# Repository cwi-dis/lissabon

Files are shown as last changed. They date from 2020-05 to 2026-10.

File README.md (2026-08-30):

# lissabon off-grid lighting control



Lissabon is an experiment in smart control over off-grid lighting. The intention is to provide a set of small dimmers, remotes and user interfaces that allow you to control lighting. The target application area is strictly low-voltage, battery operated and solar powered. 

> The project got its name from [Tuinpark Lissabon](https://www.tuinparklissabon.nl), an allotment (_"volkstuintje"_ in dutch) in Amsterdam, where the experiment was conducted... 

## Setting

The intended application area is an off-grid premise (holiday home, caravan, boat, etc) with solar cells backed by a 12V battery. Low-voltage LED lights are available as LED strips, MR-16/GU5.4 spots and various other forms, but control hardware - and especially smart home control hardware - is often geared towards use in a 110/220V environment where power is always available and not at a premium.

## Requirements

- _Day-to-day convenience_. Lights can be dimmed or turned on or off with a switch or knob on the fixture or close to it.
- _Predictiveness_. When you press the switch the light goes on or off, within a short time. 
- _Resilience_. In case of system malfunction this should be communicated to the user, and everything should go back to normal quickly. Individual lights should still be controllable on the spot. (All of this excepting a complete loss of battery power, obviously).
- _Low power consumption and very low idle power consumption_. When the lights are off the components should use very little power. So little that the individual components survive in winter, when there is preciously little sun to charge the battery, and the lights still come on when you return after a month of absence.
- _Affordable_. The cost of the control hardware should be reasonable, less than the cost of the lights they control.

The low-power requirement holds for dayly use, it is okay if the components use more power when installing new fixtures or reconfiguring the system.

## Power consumption

Preliminary analysis of the power consumption is availble in [doc/ble-power.md](doc/ble-power.md).

## Design choices

Lissabon is built on top of the [iotsa](https://github.com/cwi-dis/iotsa) Internet-of-Things framework, using the ESP32 system on a chip, which has WiFi, Bluetooth LE and low power support built in.

Lights are always eased on and off, not switched instantaneously. This looks cool, but it is also the intention that it makes the user less susceptible of any delay in operation.

> This is one of the things that needs to be tested formally.

During normal operation Bluetooth LE is used to communicate, and components are in a wake/sleep cycle. When awake they broadcast their existence with a BLE advertisement (consuming about 50mA). If not contacted within 0.2 seconds by a remote control they go into low power mode (consuming about 5mA) for 2 seconds. As the component has been inactive longer this 2 second sleep period will increase. When a local control (knob, touchpad) is operated the component awakes instantly.

> Deep sleep is not used, even though idle power consumption would go down to about 0.1mA: a wakeup from deep sleep is essentially a reboot, and would consume 100mA for about a second. This means that a deep sleep of less than 20 seconds is essentially a waste of power. This decision may be reconsidered in the future.

When the installation has to be reconfigured all components are sent a BLE instruction that will make them enable WiFi. They will keep WiFi enabled (consuming about 100mA) until they have not been contacted for 2 minutes. The configuration application (when written:-) will run on a smartphone or Raspberry PI that will also provide the WiFi Access Point (software base station).

> Using [igor](https://github.com/cwi-dis/igor) on a Raspberry PI as the basis for the control application needs to be investigated. It may be overkill, but it would allow things like waking PI once per day, and using a 3G/4G or Lorawan connection to "phone home" and report on the status of things like temperature, humidity level, battery level, etc)

## Components

### libLissabon

This is a shared library containing iotsa modules used by multiple other components. Various options are set using C-preprocessor defines, so the library is included as source in the components that actually use it.

### lissabonSimpleLight

A minimal example: a single on/off LED, controlled locally by a pushbutton and remotely over BLE. See `lissabonSimpleRemote` below.

### lissabonSimpleRemote

A minimal example: a pushbutton remote that toggles a `lissabonSimpleLight` (or any lissabon dimmer) on/off over BLE.

### lissabonDimmer

A dimmer, with buttons, touchpads, rotary control or neither. It is intended for LED lights, monochrome ledstrips or incandescant lights.

### lissabonLedstrip

A dimmer with buttons, touchpads or neither for smart (neopixel) RGB or RGBW ledstrips.

### lissabonRemote

A wireless LiPo-powered remote control that can control a predefined set of dimmers.

### lissabonController

A more elaborate remote control with a display. Incomplete. 

## Pictures

Lissabon Dimmer, plug-in variant with rotary control:
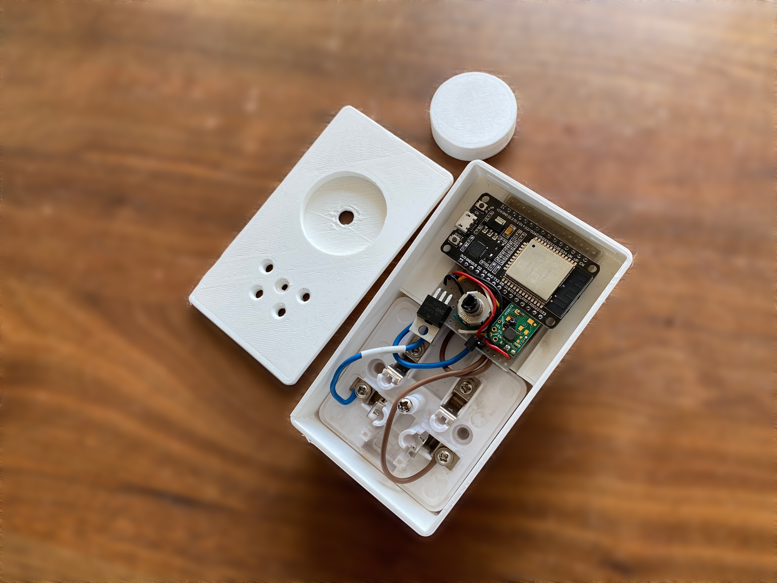
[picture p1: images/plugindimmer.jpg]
Plugin Dimmer


Lissabon Dimmer without controls, for use in inaccessible locations:
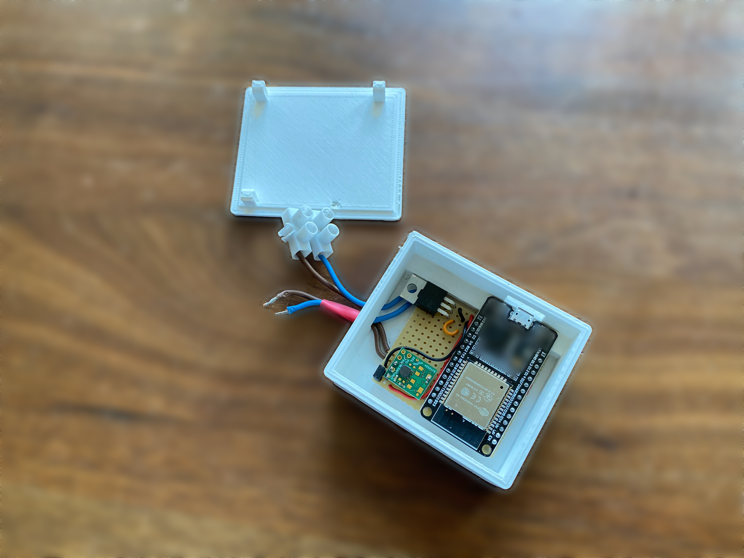
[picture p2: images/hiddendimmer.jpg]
Hidden Dimmer


Ledstrip dimmer, with brightness and color temperature touchpads:
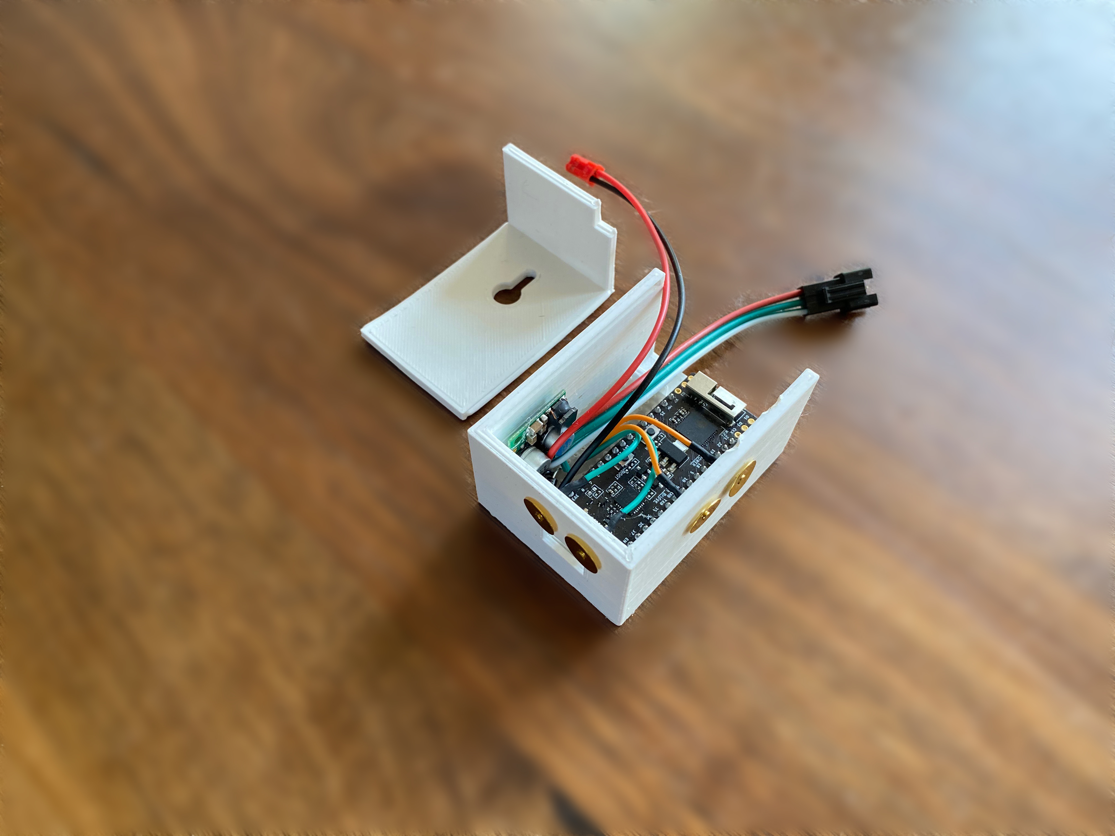
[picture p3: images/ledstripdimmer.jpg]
Ledstrip Dimmer


Wireless remote control, inside and outside with holder:
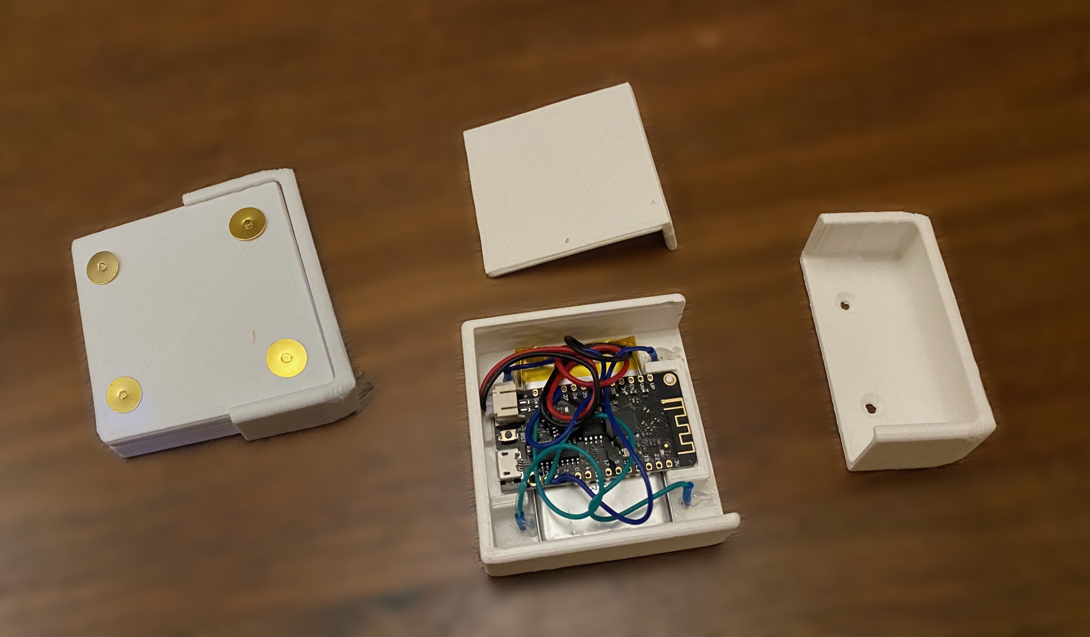
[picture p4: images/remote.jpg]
Wireless Remote


Controller: to be supplied

In situ pictures: to be supplied

## Construction notes

### Keep wiring away from the ESP32 antenna

Every lissabon appliance uses an ESP32 module with a PCB trace antenna at one end. Any
conductor in the antenna's near field (roughly 20mm, in any direction) detunes it and
costs BLE range. On deployed ledstrips, 20-35dB of lost range was traced to nothing more
than the 12V supply leads being dressed past the antenna.

This is not crosstalk: the thing being spoiled is the antenna's own tuning and
efficiency, so a pure-DC power lead does it just as well as a signal wire, and adding a
ground wire or ground pour near the antenna makes it *worse*, not better.

When building and boxing a unit:

- Mount the module so the antenna end faces open air, not the enclosure wall, the
  battery, or structural metal.
- Route *all* wiring (power and signal) out of the enclosure at the opposite end from the
  antenna.
- Twist the 12V supply pair, and twist or bundle other multi-wire runs, to minimise loop
  area.
- Orient the finished unit so the antenna end points away from any metal it is mounted on
  or near (e.g. an aluminium LED channel).

Symptom of getting this wrong: weak or highly variable BLE RSSI and connection drops that
clear up when the unit is moved or the wiring re-dressed. WiFi is far more tolerant (it
transmits ~15-20dB louder and falls back to slower bit rates), so a unit can have perfectly
good WiFi and unusable BLE from the same cause.

## ESP32 pinouts

I have been using three different boards in the various projects here. Naming of the ESP32 boards is sometimes confusing, so here are pictures of the board and their pinouts:

Lolin32 image and pinout:
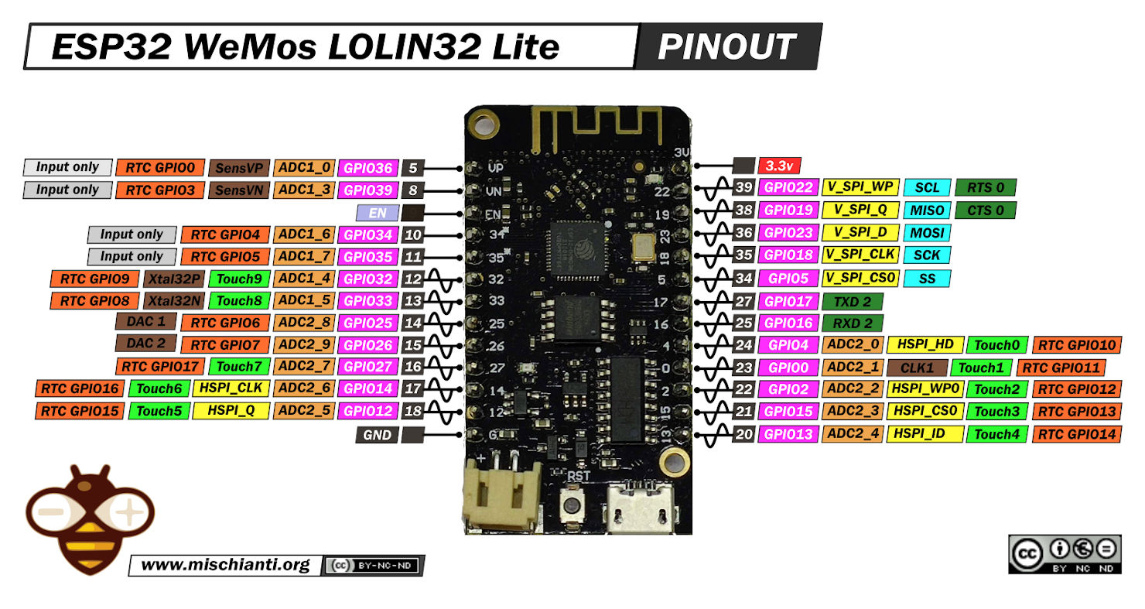
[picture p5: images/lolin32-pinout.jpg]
Lolin32 image and pinout


Esp32dev image and pinout:
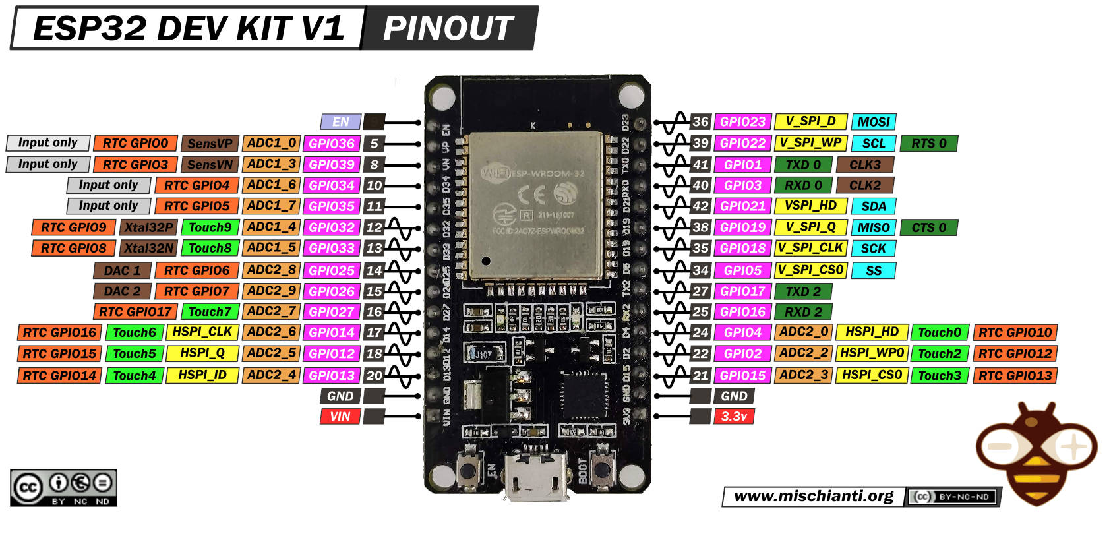
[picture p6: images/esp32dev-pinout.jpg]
esp32dev image and pinout


Pico32 image and pinout:
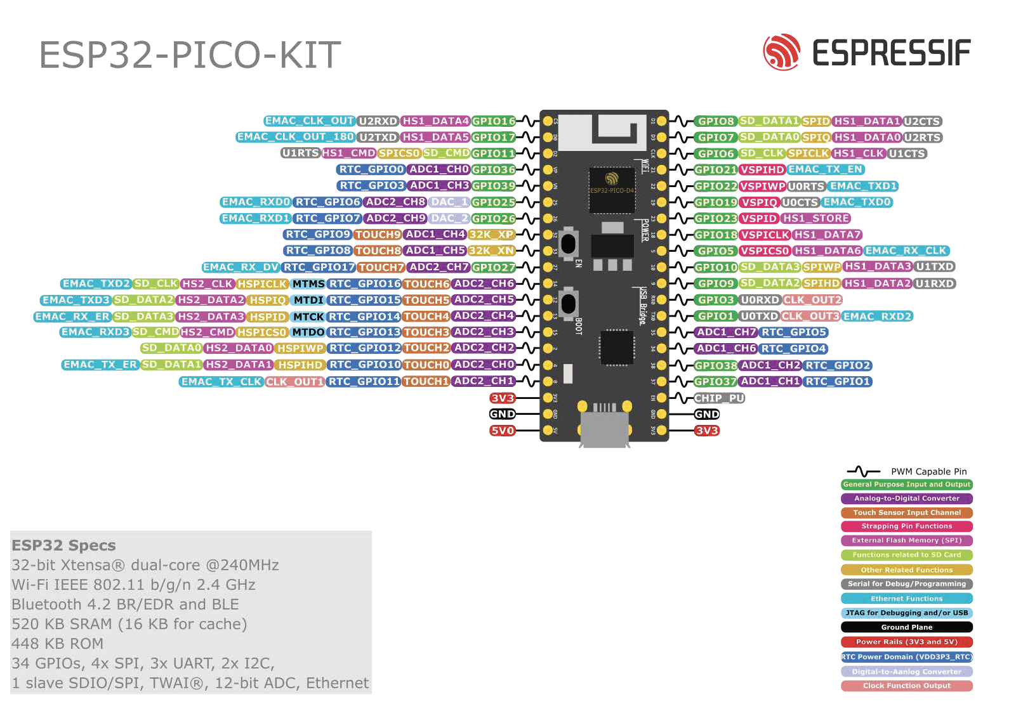
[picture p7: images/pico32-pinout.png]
pico32 image and pinout


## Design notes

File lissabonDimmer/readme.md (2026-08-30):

# lissabon Dimmer

This iotsa application implements a low-voltage dimmer using a MOSFET. Brighness 
and on/off are controlled either through a rotary encoder or through touchpads 
(selectable at build time), or even not at all (but read on).

Brightness and on/off state are inspectable and controllable over Bluetooth LE
and through a web or rest interface.

It is intended to be used in lighting applications,
probably off-grid.

## Hardware construction

The `extras` folder contains the [circuit diagram](extras/hardware_schematic.pdf) and a [stripboard layout](extras/hardware_board.pdf), plus the underlying [fritzing file](hardware.fzz).

A 3D-printable case for a dimmer without buttons or
touchpads (for installation in a ceiling or wall)
is available as a [Fusion 360 Design](extras/hidden-12v-dimmer.f3d).

There is also a 3D-printable case for a pluggable dinmmer as a [Fusion 360 Design](extras/pluggable-12v-dimmer.f3d), which works if you have wired up your 12V system using ancient KPN (dutch telephone company) plugs and outlets, but you can probably adapt it.

### Wiring and BLE range

Twist the 12V supply pair, and route it out of the enclosure at the opposite end from the ESP32 module's antenna. Supply leads dressed past the antenna have cost 20-35dB of BLE range on deployed units, with WiFi unaffected. See the top-level [README](../README.md#keep-wiring-away-from-the-esp32-antenna) for the general rule.

## Configuration

At compile time you select whether to use a rotary encoder, buttons or touchpads
to control the dimmer (depending on the hardware you built). Alternatively, if you select neither of those, you can build a dimmer that can only be controlled over WiFi or BLE (to build into a wall, for example).

## Usage

The program is setup to be built for esp32. It will be built with the _IotsaBLEServer_ module so it can be controlled over Bluetooth LE as well as WiFi. It is also built with _IotsaBattery_ so it can operate in low-power mode.

When configured for reasonable power saving options for control over bluetooth (100ms wake time, 900ms light sleep with WiFi off except for a short while after reboot or by request) the board should use around 15mA on average (not counting the output power consumption, obviously:-). 

The intention is that this allows you to use these dimmers for lighting in an off-grid 12V environment with solar cells charging a car battery without having to worry about the power consumption of the control hardware and software.

Accompanying _lissabonController_ and _lissabonRemote_ applications are also available, which will allow you to control a number of _lissabonLedstrip_ and _lissabonDimmer_ modules over Bluetooth LE.

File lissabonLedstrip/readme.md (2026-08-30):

# lissabon ledstrip controller

This iotsa application controls led strips.
It is intended mainly to be used in lighting applications, not signalling applications.

You can control the number of LEDs in the strip
and the interval between lit LEDs (to have for 
example only 1 in every 3 LED light up).

Light color can be set with either:

- RGB(W) values (numbers between 0.0 and 1.0),
- HLS values (hue as an angle between 0 and 360, lightness and saturation numbers between 0.0 and 1.0) or
-  Color temperature in Kelvin and illuminance.

Gamma correction can be applied (a value of 2.2 or 2.8 seems
to be commonly suggested for NeoPixel LEDs).

Changing the color will do a fairly fast gradual
crossfade from the old color to the new one.

When configured for RGBW LEDs and using the temperature/illuminance control an illuminance of 1.0 means "as much light as possible", i.e. it will use all 4 LEDs as much as possible. In this use case you can also configure the temperature of the White LED so the resulting color temperature should be fairly correct.

## configuration

To change the type of NeoPixel (default GRB 800KHz,
the most common type) or the output pin to which the strip is connected (default GPIO 13) you have to recompile it.

## construction

The `extras` folder has Fritzing files for a 4-touchpad (dimmer/off, brighter/on, warmer, cooler) circuit, for either 12V or 5V RGBW strips. Also available as PDF, [5V circuit](extras/Hardware-5v.pdf) and [12V circuit](extras/Hardware-12v.pdf).

There is also a Fusion 3D project for a 3D-printable case.

### 5V vs 12V strips

The firmware variant (`lissabon-5v-ledstrip` vs `lissabon-12v-ledstrip`) determines the NeoPixel colour order:

- **5V strips** (e.g. cheap Chinese RGBW strips): `NeoGrbwFeature` — build with `lissabon-5v-ledstrip`
- **12V strips** (e.g. ENTTEC RGBW strips): `NeoRgbwFeature` — build with `lissabon-12v-ledstrip`

**Safety: reversed connector for 12V.** To prevent accidentally plugging a 5V strip into a 12V controller (which would destroy it), the 12V hardware uses a reversed connector polarity — male on the controller side, female on the strip side (or vice versa). Make sure any replacement 12V strip uses the same reversed connector.

### Wiring and BLE range

Twist the 12V supply pair, and route it (and the strip leads) out of the enclosure at the opposite end from the ESP32 module's antenna. Supply leads dressed past the antenna have cost 20-35dB of BLE range on deployed units, with WiFi unaffected. See the top-level [README](../README.md#keep-wiring-away-from-the-esp32-antenna) for the general rule.

## usage

The program is setup to be built for esp32. It will be built with the _IotsaBLEServer_ module so it can be controlled over Bluetooth LE as well as WiFi. It is also built with _IotsaBattery_ so it can operate in low-power mode.

When configured for reasonable power saving options for control over bluetooth (100ms wake time, 900ms light sleep with WiFi off except for a short while after reboot or by request) the board should use around 15mA on average (not counting the LED power consumption, obviously:-). Formal power consumption measurements will be made later.

The intention  is that this allows you to use these LED strips for lighting in an off-grid 12V environment with solar cells charging a car battery without having to worry about the power consumption of the control hardware and software.

Accompanying _lissabonController_ and _lissabonRemote_ applications are also available, which will allow you to control a number of _lissabonLedstrip_ and _lissabonDimmer_ modules over Bluetooth LE.

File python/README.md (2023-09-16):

# lissabonCalibrate

Calibrate lissabon ledstrips.

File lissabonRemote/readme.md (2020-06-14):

# BLE Dimmer

This module can used to build a battery-operated remote controller (using BLE)
for iotsaDimmer or iotsaLedstrip devices. IotsaBLEDimmer will have two touchpads
functioning as off/on on a short touch and intensity down/up on a long press.
Which iotsaDimmer or iotsaLedstrip is controlled can be set through the
web interface or REST API. Optionally more dimmers can be controlled
with extra touchpads.

The intention is that this device is normally powered from a LiPo
battery, without WiFi, and in hibernate mode until a button is touched.
That way, the battery life should be months.

To recharge the iotsaBLEDimmer is attached to USB to recharge the LiPo.
When powered from USB WiFi will be enabled and the device can be configured,
for example to assign the iotsaDimmer or iotsaLedstrip the device controls.

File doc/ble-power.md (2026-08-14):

# Power consumption

## BLE power measurements

A set of measurements have been done with a pico32 board connected to a 5V power supply. The red LED on the board had not been removed, so the idle power consumption is a bit too high. This is the board that is used in the ledstrip devices, the board used in the dimmers is different (esp32dev) and will need to be measured separately.

**Note (2026-07-19):** the `sleepDuration`/`wakeDuration` values below (800/80) are what this specific historical measurement session used on a bench-test device (`striphome`, not a currently-deployed device name) -- they are not today's fleet default. Deployed devices now use `sleepDuration=1500`, `wakeDuration=300` (verified against `../../lissabon-config/*/battery.json`), a tighter cycle chosen for better responsiveness -- see `../../iotsa/docs/ble-power-vs-responsiveness.md` for why that tradeoff was made. The graphs and power numbers below are accurate to the 800/80 configuration they were actually captured under and haven't been re-measured at 1500/300; treat the *shape* of the analysis (boot spike, sleep/wake duty cycle, connect behavior) as still representative, but don't read the specific millisecond figures as current.

The device had WiFi disabled, and the following parameters for battery and bleserver:

```
striphome:
  bleserver:
    isEnabled:       True
    adv_min:         30
    adv_max:         30
    tx_power:        -1
```

**Note (2026-08-14):** `tx_power` above is the field name at the time of this
capture. It's since been renamed to `tx_power_dbm` (a requested value, user/REST-settable,
persisted) plus a new read-only `tx_power_dbm_actual` (read back from the hardware via
`getPower()`) -- see cwi-dis/iotsa#164. The `-1` value itself means the same thing
before and after the rename (leave transmit power at the hardware default).

```
striphome:
  battery:
    sleepMode:       2
    sleepDuration:   800
    wakeDuration:    80
    bootExtraWakeDuration: 10000
    activityExtraWakeDuration: 2000
    postponeSleep:   2000
    watchdogDuration: 0
    levelVBat:       0
    correctionVBat:  1
    disableSleepOnWiFi: False
```

Or in english: atfer boot stay awake for 10 seconds, then go into a pattern of 80ms awake, 800ms light sleep. After any activity stay awake for an extra 2 seconds. While awake (and not BLE-connected) send out advertisements every 20ms.

Here is the graph of power consumption during boot:

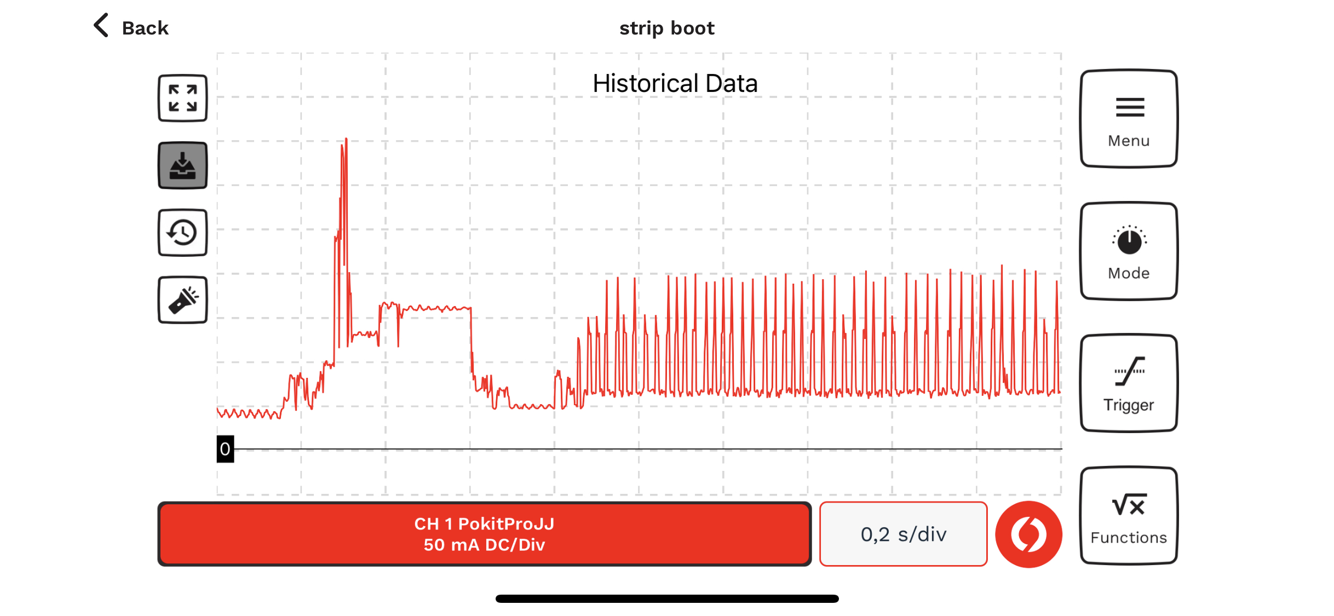
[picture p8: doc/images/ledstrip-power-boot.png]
Power consumption during boot


Or in english: boot takes 600ms with a spike of 350mA, then 150mA for 200mS, then 50mA for 200mS. Then we get into a pattern of spikes of 200mA (advertisement, BLE radio transmitter on) and 60mA otherwise (BLE radio receiver on).

After 10 seconds we go to the normal pattern where we advertise for a bit (and possibly get a connection request) and then go to light sleep for a much longer bit:

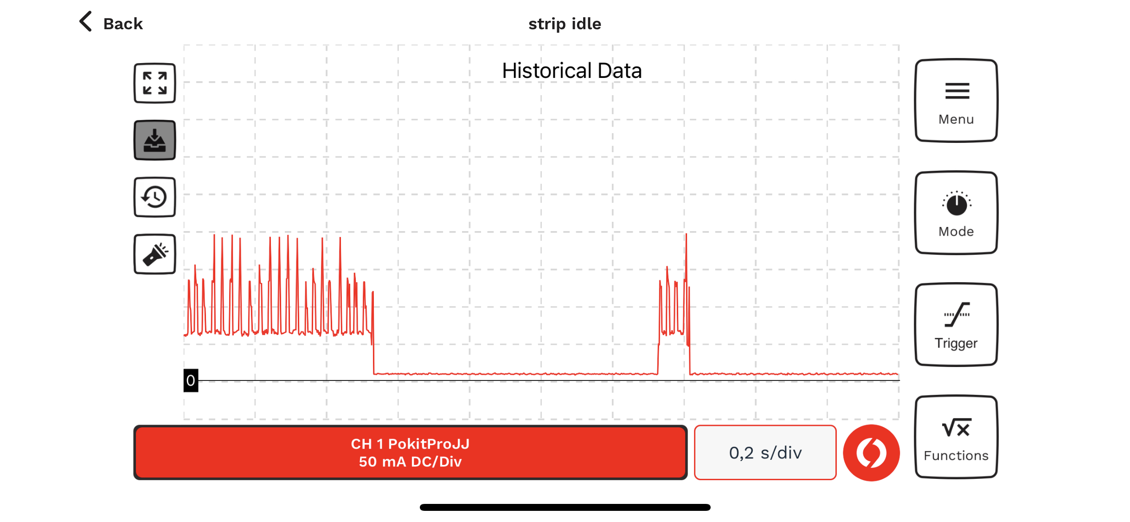
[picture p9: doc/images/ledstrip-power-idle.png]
Power consumption when idle


Or in english: 800mS of light sleep using 7mA, then 80mS of using 60mA (BLE radio receiving) with spikes of 150-200mA (BLE radio transmitting advertisement).

Summarizing: this should give an average power consumption of 13mA at 5V. So in situ, with a Pololu regulator and the LED removed we expect to use about 6mA at 12V.

For completeness here is the data for a BLE connect:

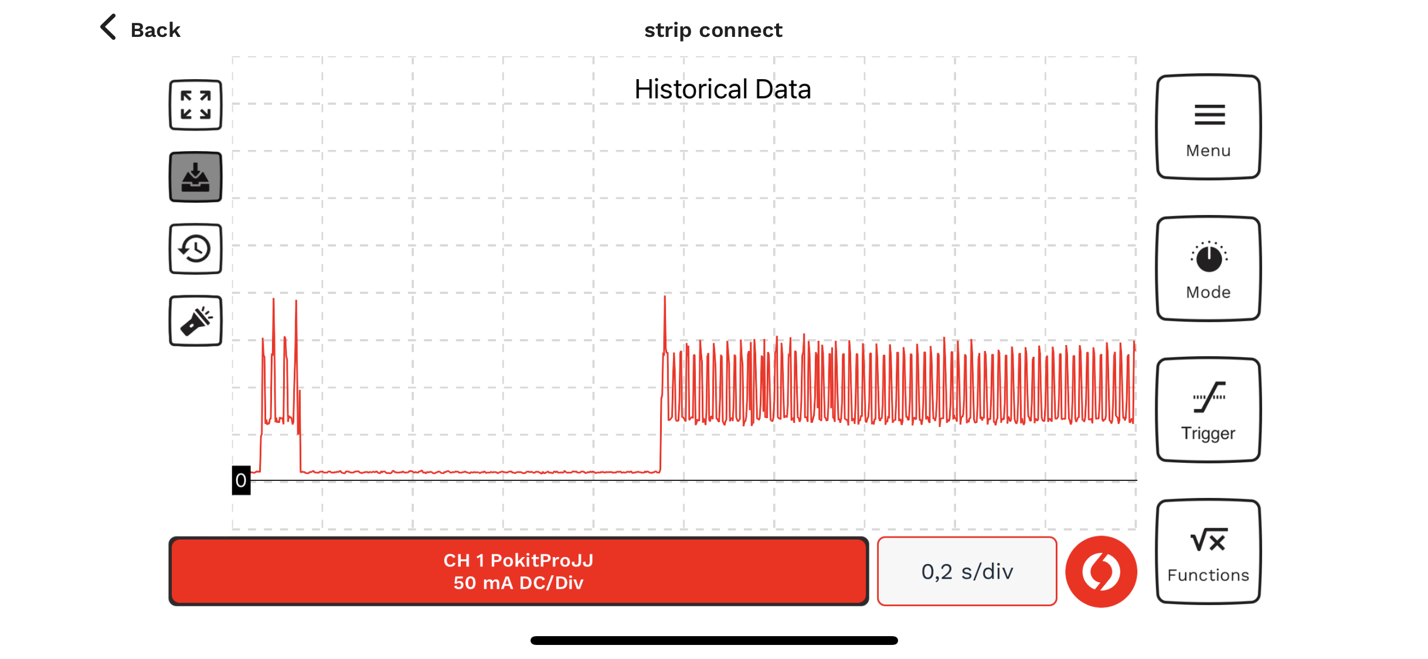
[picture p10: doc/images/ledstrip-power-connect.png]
Power consumption during connect


Again: 60mA with the receiver on and 150mA with the transmitter on (but note that the interval between transmissions is now the BLE Connection interval, which is apparently 15mS).

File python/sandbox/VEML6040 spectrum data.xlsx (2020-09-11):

 |  |  |  | LED source |  |  | IT = 100ms | Red | Green | Blue
veml6040 Spectrum |  | Red | 56 uW/cm2 | Peak | Wavelength(nm) |  | Responsivity | 96 | 74 | 56 | counts/uW/cm2
 |  | Green | 32.7 uW/cm2 | R | 619 | nm
 |  | Blue | 84 uW/cm2 | G | 517.5 | nm |  |  |  |  |  |  |  | Normalized
 | Relative Responsivity |  |  | B | 466.5 | nm
 | Red | Green | Blue |  |  |  |  |  |  |  |  |  |  | R | G | B | W
400 | 330.2241003 | 157.8405763 | 727.6973061 |  |  |  |  |  |  |  |  |  | 400 | 0.02536990617 | 0.01260197423 | 0.1102136382 | 0.3222654361
401.6620499 | 360.2319815 | 180.382975 | 806.7668635 |  |  |  |  |  |  |  |  |  | 401.6620499 | 0.0276753016 | 0.01440175686 | 0.1221891444 | 0.33476899
403.3240997 | 386.0136677 | 200.7272695 | 860.5951108 |  |  |  |  |  |  |  |  |  | 403.3240997 | 0.02965601397 | 0.01602604309 | 0.1303417196 | 0.349702065
404.9861496 | 375.8708874 | 217.1700216 | 914.162585 |  |  |  |  |  |  |  |  |  | 404.9861496 | 0.02887678137 | 0.01733883061 | 0.1384547993 | 0.3555803621
406.6481994 | 422.3980497 | 274.9657082 | 979.3804619 |  |  |  |  |  |  |  |  |  | 406.6481994 | 0.03245129256 | 0.02195323186 | 0.1483323946 | 0.3639257234
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

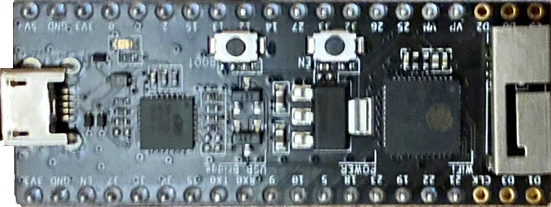
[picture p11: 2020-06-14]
lissabonLedstrip/extras/images/esp32-pico-kit.png

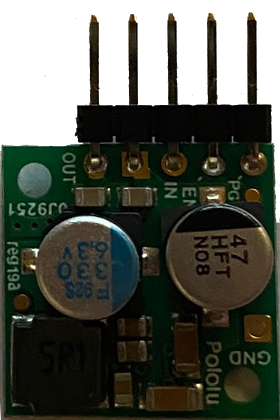
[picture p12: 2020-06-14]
lissabonLedstrip/extras/images/pololu.png

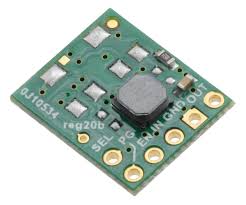
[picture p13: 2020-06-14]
lissabonDimmer/extras/Pololu-S9V11F3S5.jpeg

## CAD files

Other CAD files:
lissabonDimmer/extras/hidden-12v-dimmer.f3d
lissabonDimmer/extras/pluggable-12v-dimmer.f3d
lissabonLedstrip/extras/Ledstrip-controller-case.f3d

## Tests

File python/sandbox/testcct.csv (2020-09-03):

requested | rgb_lux_10 | rgb_cct_10 | rgb_lux_20 | rgb_cct_20 | rgb_lux_50 | rgb_cct_50 | rgb_lux_100 | rgb_cct_100 | parameter | value
2000.0 | 27.14998 | 2302 | 31.49146 | 2180 | 59.9313 | 1748 | 176.1445 | 1503
2500.0 | 27.18144 | 2320 | 31.55438 | 2189 | 67.19856 | 1963 | 213.7078 | 1821
3000.0 | 28.50276 | 2412 | 32.93862 | 2314 | 75.59838 | 2221 | 254.7316 | 2197
3500.0 | 28.28254 | 2409 | 35.26666 | 2487 | 84.65886 | 2523 | 295.7869 | 2585
4000.0 | 28.7859 | 2478 | 35.45542 | 2529 | 92.90138 | 2811 | 336.0557 | 2985
4500.0 | 28.66006 | 2480 | 36.14754 | 2559 | 102.3394 | 3111 | 375.4122 | 3372
5000.0 | 28.59714 | 2488 | 36.4936 | 2659 | 111.3369 | 3408 | 414.6113 | 3751
5500.0 | 28.59714 | 2490 | 38.34974 | 2775 | 118.8244 | 3695 | 449.9409 | 4122
6000.0 | 28.43984 | 2485 | 39.92274 | 2899 | 126.6894 | 3952 | 483.8863 | 4471
6500.0 | 28.21962 | 2476 | 40.36318 | 2975 | 134.3657 | 4223 | 518.0518 | 4826
7000.0 | 28.1567 | 2484 | 38.79018 | 3023 | 127.9478 | 4450 | 489.5805 | 5320
 |  |  |  |  |  |  |  |  | measurement | rgb_cct
 |  |  |  |  |  |  |  |  | interval
 |  |  |  |  |  |  |  |  | rgb_gamma | 1

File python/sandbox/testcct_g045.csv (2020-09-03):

requested | rgb_lux_10 | rgb_cct_10 | rgb_lux_20 | rgb_cct_20 | rgb_lux_50 | rgb_cct_50 | rgb_lux_100 | rgb_cct_100 | parameter | value
2000.0 | 51.64159 | 2278 | 75.20513 | 2232 | 144.6688 | 2181 | 266.3561 | 2150
2500.0 | 56.69092 | 2618 | 85.36671 | 2661 | 153.9967 | 2711 | 321.0965 | 2742
3000.0 | 59.1448 | 2842 | 93.82945 | 3001 | 194.8318 | 3138 | 356.2688 | 3191
3500.0 | 63.09303 | 3080 | 100.1529 | 3275 | 211.3955 | 3472 | 393.8949 | 3562
4000.0 | 64.72895 | 3202 | 105.7371 | 3518 | 224.939 | 3760 | 421.8629 | 3881
4500.0 | 67.23002 | 3384 | 109.4336 | 3712 | 236.7208 | 4022 | 445.8197 | 4148
5000.0 | 127.6804 | 3840 | 113.3976 | 3927 | 246.6936 | 4235 | 464.8215 | 4374
5500.0 | 69.3693 | 3678 | 106.9955 | 4023 | 256.1473 | 4434 | 481.5425 | 4572
6000.0 | 71.63442 | 3808 | 119.9413 | 4257 | 260.4731 | 4619 | 497.8388 | 4756
6500.0 | 72.18497 | 3940 | 122.3951 | 4391 | 271.9874 | 4795 | 513.0025 | 4926
7000.0 | 70.51759 | 3990 | 119.2649 | 4465 | 266.0415 | 4916 | 503.8162 | 5190
 |  |  |  |  |  |  |  |  | measurement | rgb_cct
 |  |  |  |  |  |  |  |  | interval
 |  |  |  |  |  |  |  |  | rgb_gamma | 0.45

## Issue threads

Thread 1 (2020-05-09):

Code needs to be refactored out the other various lissabon tools

jackjansen, 2020-05-09:
There's various bits of common code that need to go to a common place (probably this repo):
- Dimmer UI, both touchpad and rotary encoder (used by lissabonRemote and lissabonDimmer, maybe lissabonController)
- BLEDimmer, BLEClient, BLEClientConnection (used by lissabonRemote and lissabonController)
- BLE server interface (Dimmer and LedStrip)

jackjansen, 2021-04-04:
Pretty much fixed quite some time ago (when the subsidiaries moved into this repo).

Closed 2021-04-04.

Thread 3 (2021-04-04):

BLE discovery doesn't find names (at least not always)

jackjansen, 2021-04-04:
There's an issue with BLE discovery that it doesn't find the name of the device, at least not always.

I vaguely remember that this has to do with an issue in the BLE library, but I can't remember for sure. Need to hunt for it (especially because I also seem to remember that I had a workaround).

jackjansen, 2021-08-07:
Disabling the light sleep in the dimmers has worked around this issue.

jackjansen, 2022-07-23:
This seems to be fixed with the move to nimble.

Closed 2022-07-23.

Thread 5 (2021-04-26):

BLE scanning monopolizes radio (and uses too much power)

jackjansen, 2021-04-26:
In IotsaBLEClient, if a known device is offline, it will scan continuously (except for the ble/wifi radio sharing implemented at the low level).

If this happens connecting to a known network may still work, but creating a softAP doesn't.
Also, this eats batteries.

We should hold off scanning at some point, even if we haven't found all devices yet.

jackjansen, 2022-06-24:
This appears fixed by switching to nimble.

Closed 2022-06-24.

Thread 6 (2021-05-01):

OTA runs afoul of watchdog timer

jackjansen, 2021-05-01:
For reasons I don't understand yet it seems like OTA hits the watchdog timer (even though there are feed calls in the oat callbacks).

jackjansen, 2021-08-07:
Fixed in iotsa.

Closed 2021-08-07.

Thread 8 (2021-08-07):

Dim pixel on led strips that are turned off need a different fix.

jackjansen, 2021-08-07:
There is now code to ensure that a lissabonLedstrip that is turned off and disconnected from power no longer has a dimly lit first pixel.

But the code is a gross hack, it's hand-coded `gpio_matrix_out` calls that happen to work with this specific board and pins.

NeoPixelBus has a partial fix, but not a complete one.

If https://github.com/Makuna/NeoPixelBus/issues/510 is accepted and fixed we can simply delete and re-create the NeoPixelBus.

jackjansen, 2021-08-11:
Branch created, and fix confirmed.

Merge branch when new version of NeoPixelBus is released.

jackjansen, 2022-07-23:
I think this is fixed.

Closed 2022-07-23.

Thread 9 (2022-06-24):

ledStrips with newest software don't react to changes

jackjansen, 2022-06-24:
Whether the changes (on/off, level) go over BLE or HTTP they don't have an effect. But they do show up when you interrogate the device later (over BLE or HTTP), and they _will_ be implemented if you do something like sending an identify to the device.

jackjansen, 2022-06-24:
The spots (which still run the old software) do react to on/off, but behave funnily with respect to brightness.

jackjansen, 2022-07-16:
Fixed in 932847 but the controller problem was separately fixed in df91ee7

Closed 2022-07-16.

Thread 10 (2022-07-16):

Issue with rotary encoder

jackjansen, 2022-07-16:
I think there is an issue with the rotary encoder (so really a iotsa issue probably). When you rotate quickly the encoder value goes in the wrong direction.

Very clear with the lissabonController but I think I've also seen it with the plugin dimmers.

Closed 2022-07-19.

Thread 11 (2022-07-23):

Use rocker switch in lissabonController for selecting dimmer to control.

jackjansen, 2022-07-23:
The current usage of press-rotate the rotary encoder is not intuitive.
Also, adding a rocker switch would free up press-rotate for changing the color temperature.

jackjansen, 2023-04-30:
Implemented.

Closed 2023-04-30.

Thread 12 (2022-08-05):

lissabonLedstrips Colors are incorrect

jackjansen, 2022-08-05:
Subject says all.

First thing I've noticed: the W led is driven too hard.

Example command:

```
iotsaControl --target stripdeur xConfig ledstrip level=0.5 temperature=4000  whiteBrightness=1 calibrationMode=2 xInfo ledstrip xInfo pixels
```

Output from `xInfo pixels`, which has alternating RGBW and RGB values:

```
  data:            [0, 0, 0, 255, 127, 102, 83, 0, 0, 0, 0, 255, 127, 102, 83, 0]
```

but this may be an issue with `calibrationMode` (because the RGB pixels are computed for `maximum=1` but they should be computed for `maximum=2`.)

jackjansen, 2022-08-05:
Fixing calibrationMode to take the W brightness into account (by using level `curLevel * (1+rgbwSpace.WBrightness)`) does not solve the issue. It makes it less, but doesn't solve it:

```
iotsaControl --target stripdeur xConfig ledstrip temperature=6500  level=0.4 xInfo ledstrip xInfo pixels
```

gives

```
stripdeur.local:
  whiteTemperature: 4000
  whiteBrightness: 1
  focalPoint:      0.5
  focalSpread:     0
  maxLevelCorrectColor: 0.824182987
  maxLevelCorrectColorTemperature: 6500
  calibrationMode: 2
  name:    
  available:       True
  isOn:            True
  level:           0.400000006
  minLevel:        0
  gamma:           1
  animation:       0
  temperature:     6500
stripdeur.local:
  data:            [0, 32, 57, 173, 102, 101, 100, 0, 0, 32, 57, 173, 102, 101, 100, 0]

```

jackjansen, 2023-04-30:
This seems pretty good by now.

Closed 2023-04-30.

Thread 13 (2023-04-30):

Ledstrip gamma interferes with curves

jackjansen, 2023-04-30:
The current way it is implemented (by applying the gamma to the `level` variable in the dimmer) doesn't work: the maximum is going to be throttled by the maximum level that is attainable for the current color temperature.

The problem may be in the color curve calculation, too.

jackjansen, 2023-05-07:
This has been fixed by recomputing the RGBW value for every pixel, depending on temperature and level. Turns out the esp32 is fast enough to do this (checked by putting debug prints in that show how many micros are spent in loop()).

Closed 2023-05-07.

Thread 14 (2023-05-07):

Controller things to be done

jackjansen, 2023-05-07:
Various:

- [ ] better callbacks from BLEDimmer (probably with dimmer as argument)
- [ ] better callbacks for scanning
- [ ] Investigate using a task for BLEDimmer
- [ ] Save currently selected dimmer (possibly only when changing something?)
- [ ] see what happens if we go to deep sleep/hibernate.

jackjansen, 2023-05-20:
There's sample code for using tasks referenced in https://github.com/h2zero/NimBLE-Arduino/issues/536

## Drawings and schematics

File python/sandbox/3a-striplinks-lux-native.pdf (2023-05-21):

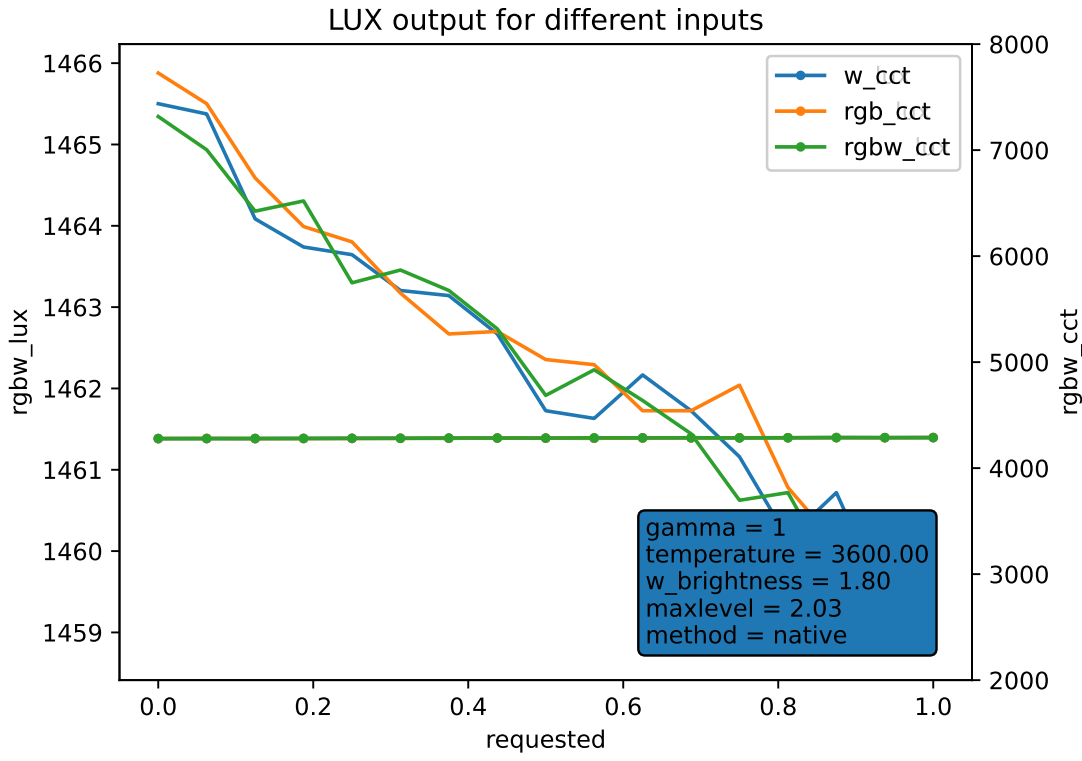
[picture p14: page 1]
requested; rgbw_lux; gamma = 1 temperature = 3600.00 w_brightness = 1.80 maxlevel = 2.03 method = native; w_lux rgb_lux rgbw_lux; rgbw_cct; w_cct rgb_cct rgbw_cct

LUX output for different inputs

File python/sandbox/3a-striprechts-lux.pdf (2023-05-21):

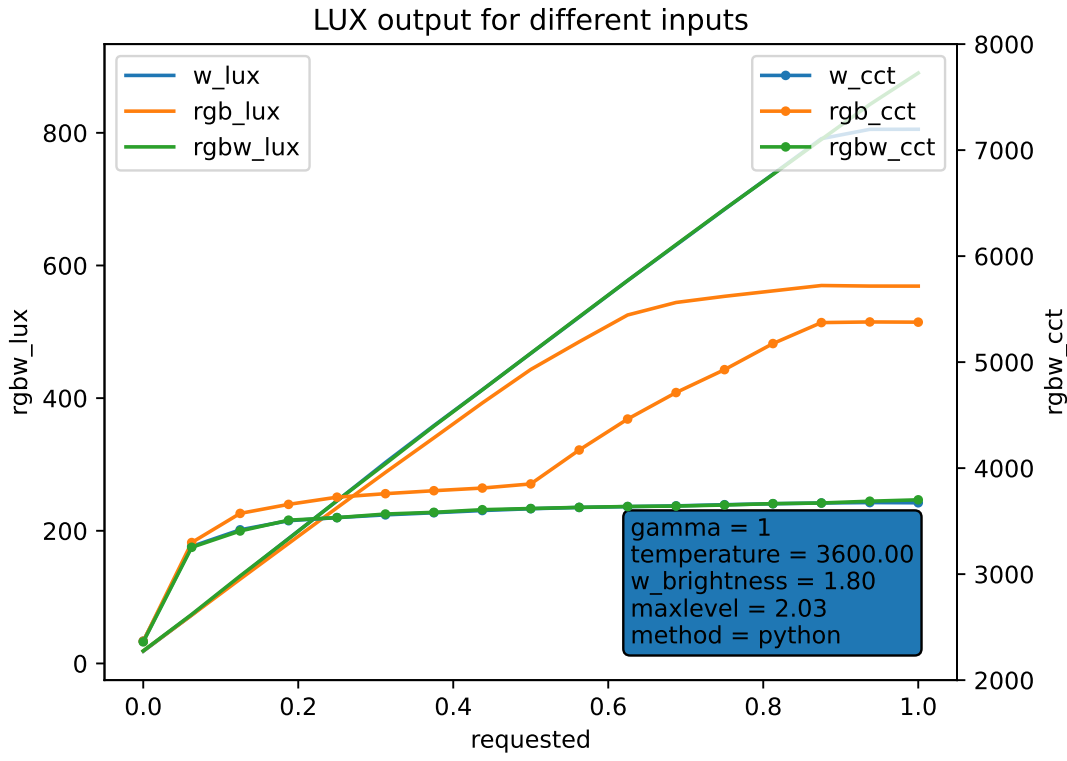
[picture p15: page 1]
requested; rgbw_lux; gamma = 1 temperature = 3600.00 w_brightness = 1.80 maxlevel = 2.03 method = python; w_lux rgb_lux rgbw_lux; rgbw_cct; w_cct rgb_cct rgbw_cct

LUX output for different inputs

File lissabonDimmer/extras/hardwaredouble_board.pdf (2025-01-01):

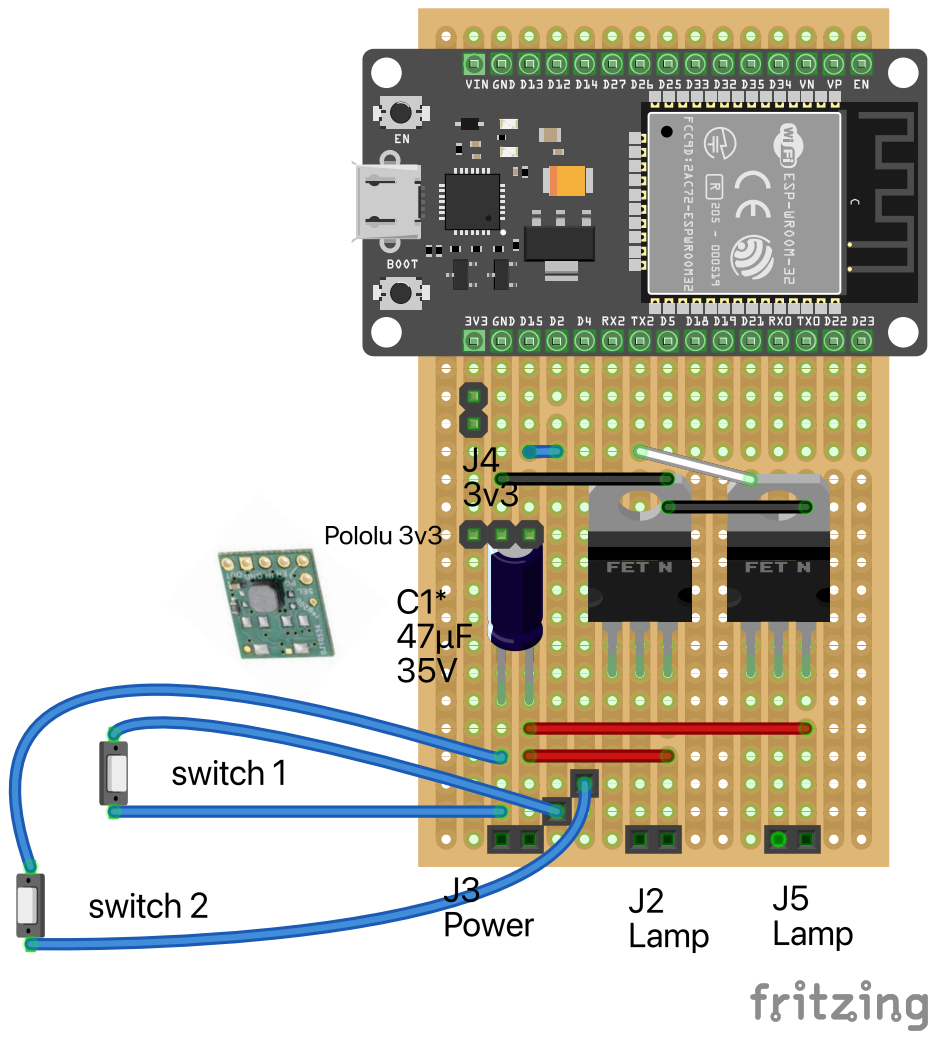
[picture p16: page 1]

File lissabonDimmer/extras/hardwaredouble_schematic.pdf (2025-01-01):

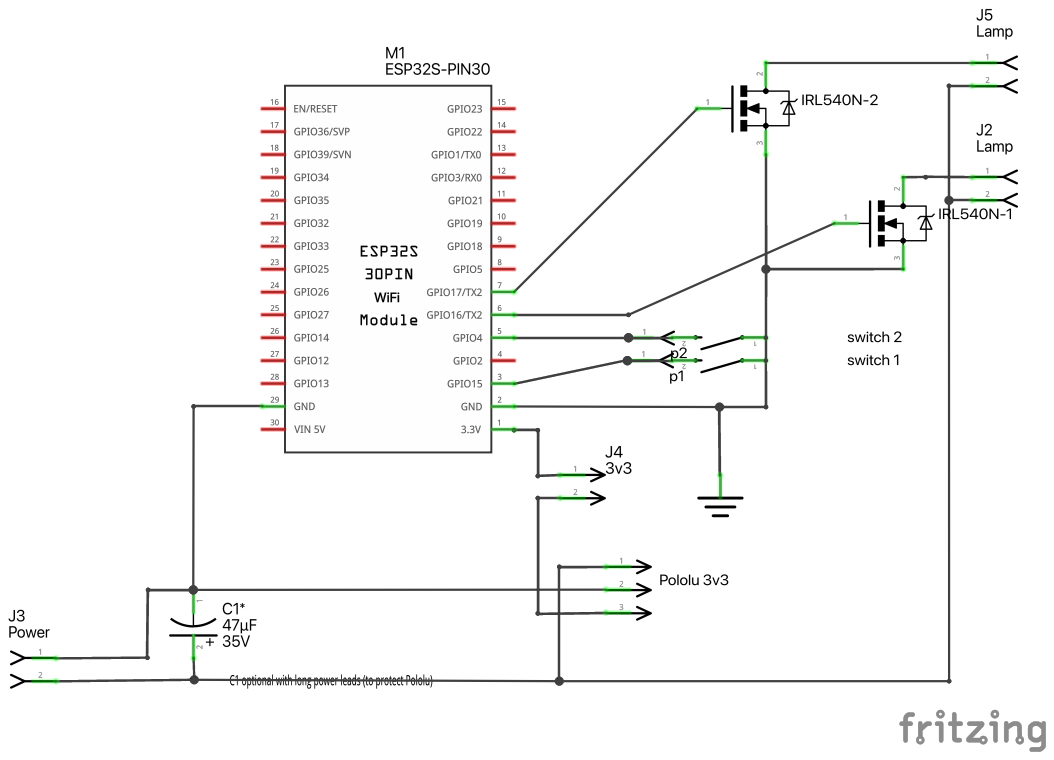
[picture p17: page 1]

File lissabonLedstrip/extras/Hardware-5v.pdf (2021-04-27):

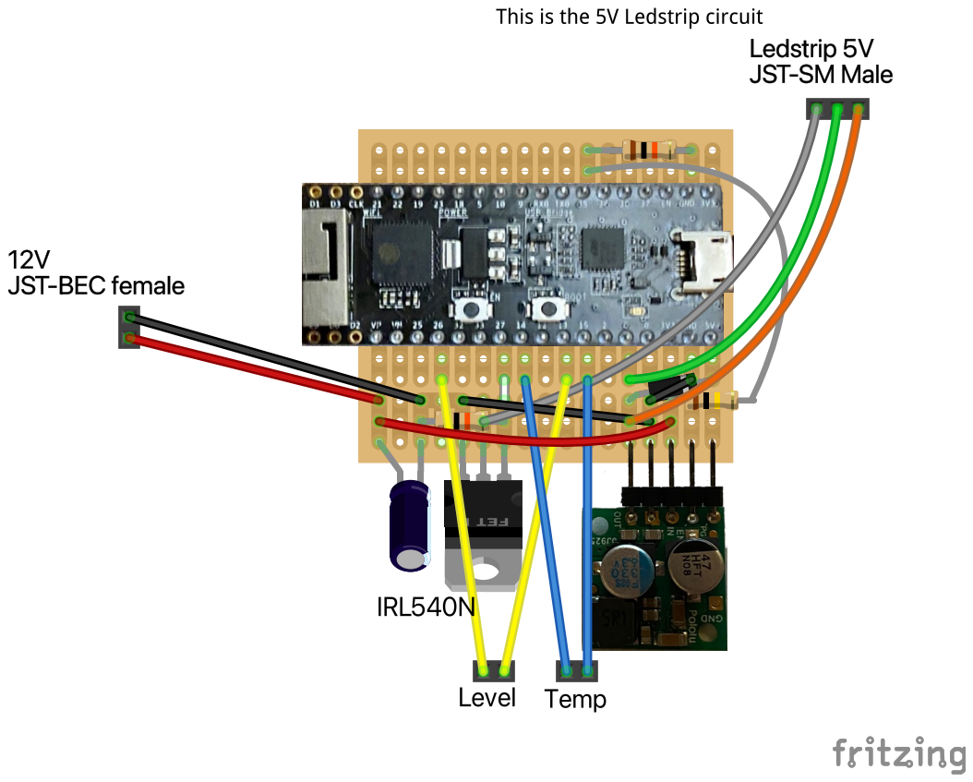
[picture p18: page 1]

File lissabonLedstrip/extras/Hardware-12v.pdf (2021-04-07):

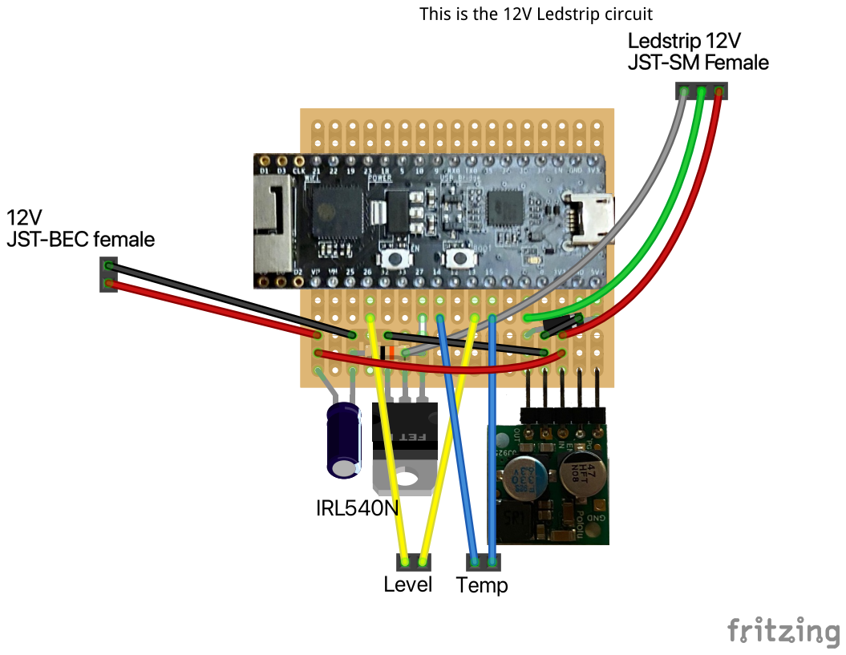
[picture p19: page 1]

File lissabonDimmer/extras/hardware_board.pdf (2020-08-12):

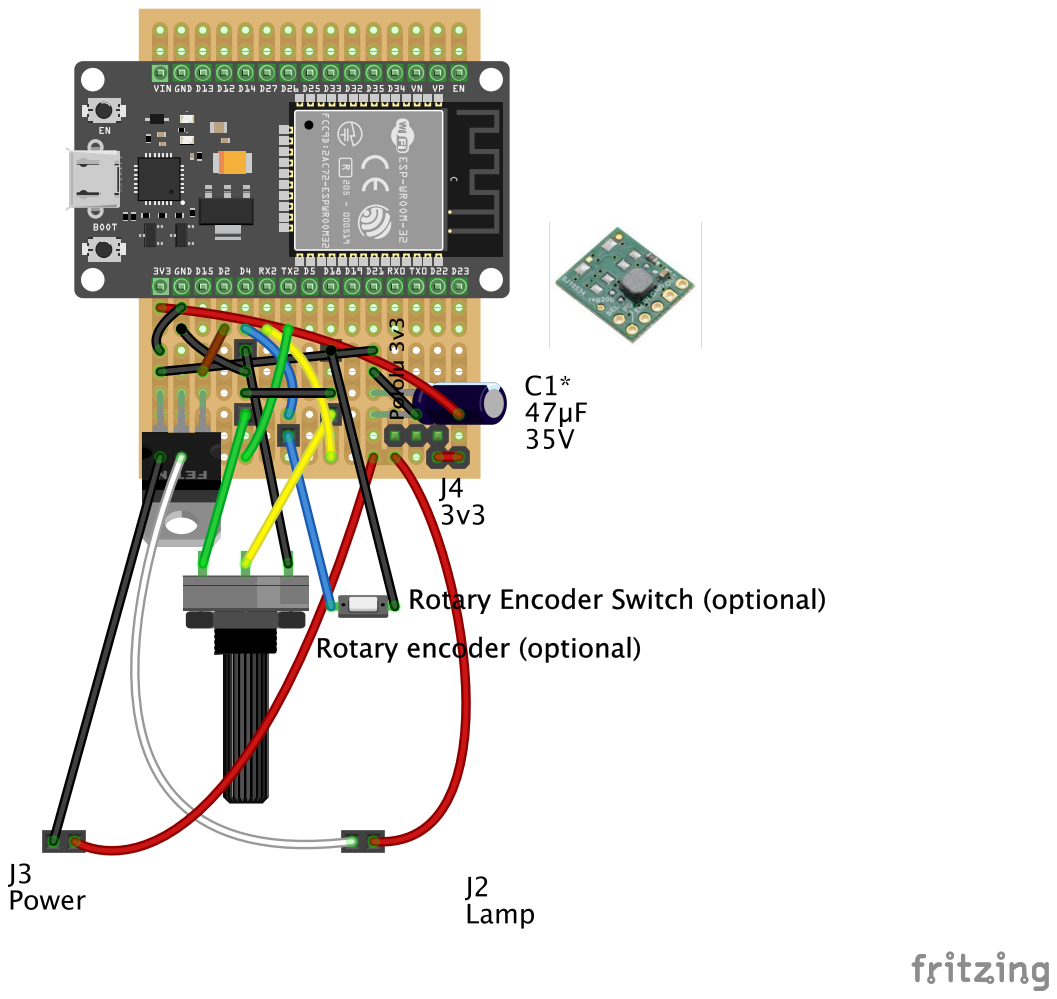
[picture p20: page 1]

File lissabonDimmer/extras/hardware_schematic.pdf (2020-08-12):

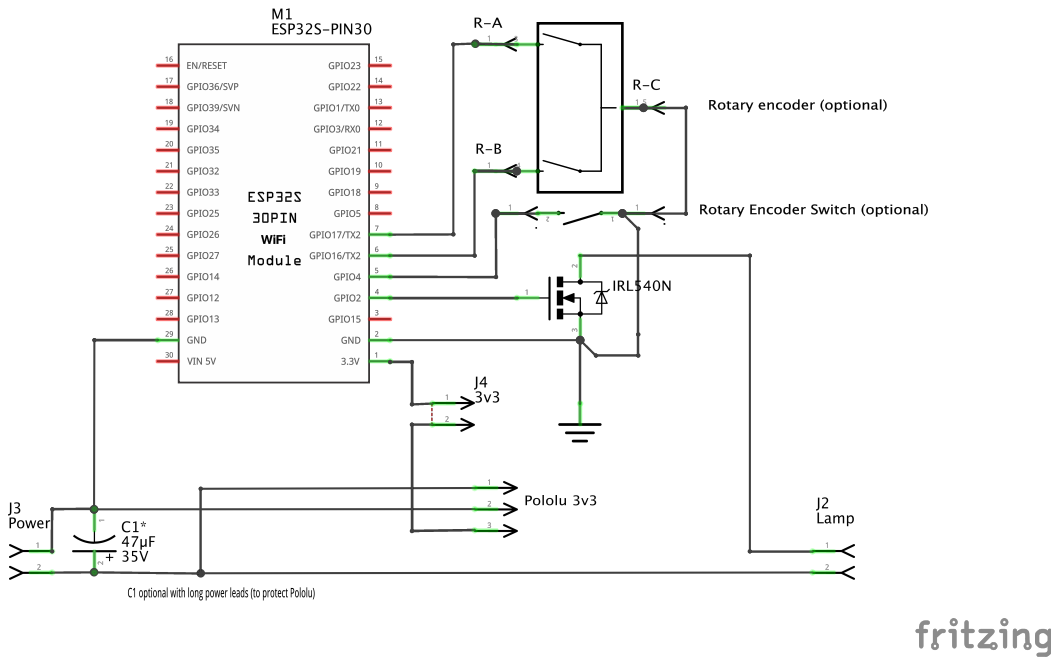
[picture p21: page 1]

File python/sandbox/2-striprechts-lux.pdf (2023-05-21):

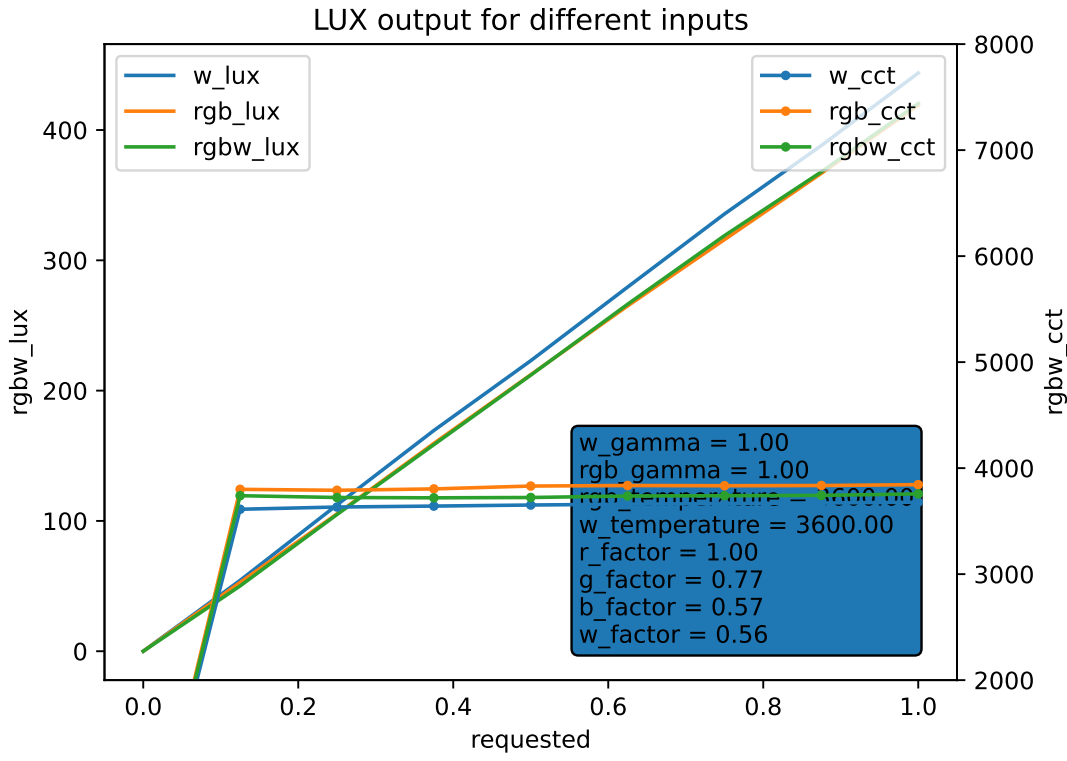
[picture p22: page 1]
requested; rgbw_lux; w_gamma = 1.00 rgb_gamma = 1.00 rgb_temperature = 3600.00 w_temperature = 3600.00 r_factor = 1.00 g_factor = 0.77 b_factor = 0.57 w_factor = 0.56; w_lux rgb_lux rgbw_lux; rgbw_cct; w_cct rgb_cct rgbw_cct

LUX output for different inputs

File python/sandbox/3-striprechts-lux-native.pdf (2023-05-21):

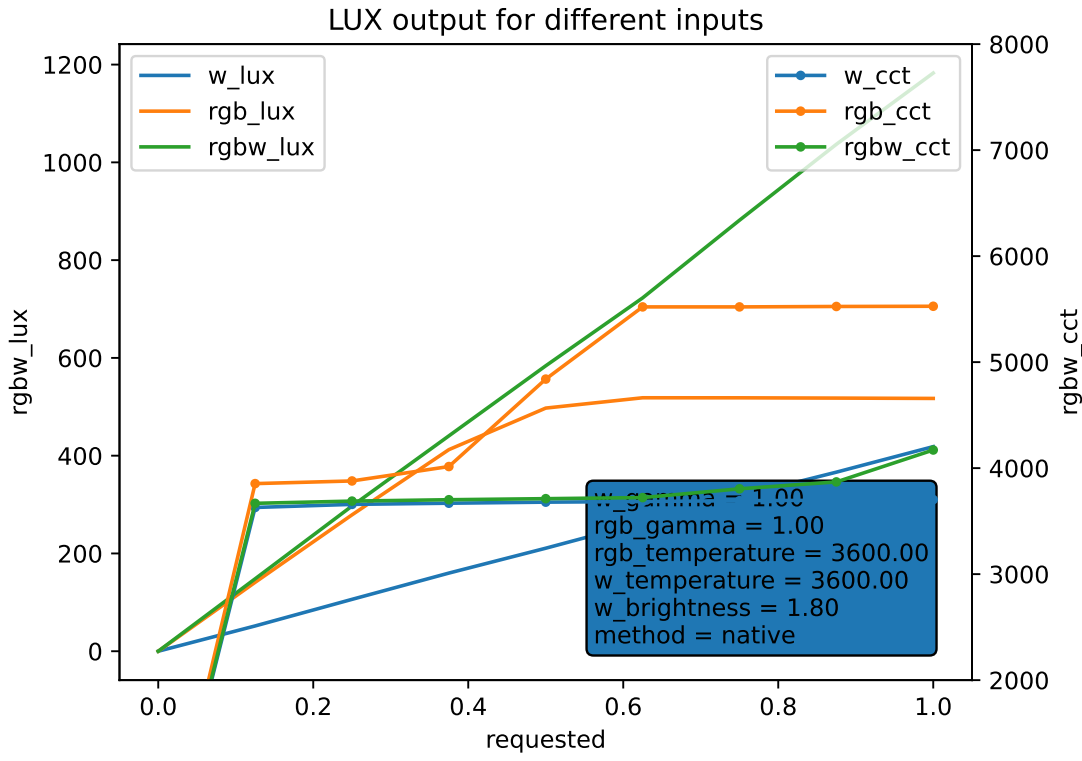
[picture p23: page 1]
requested; rgbw_lux; w_gamma = 1.00 rgb_gamma = 1.00 rgb_temperature = 3600.00 w_temperature = 3600.00 w_brightness = 1.80 method = native; w_lux rgb_lux rgbw_lux; rgbw_cct; w_cct rgb_cct rgbw_cct

LUX output for different inputs

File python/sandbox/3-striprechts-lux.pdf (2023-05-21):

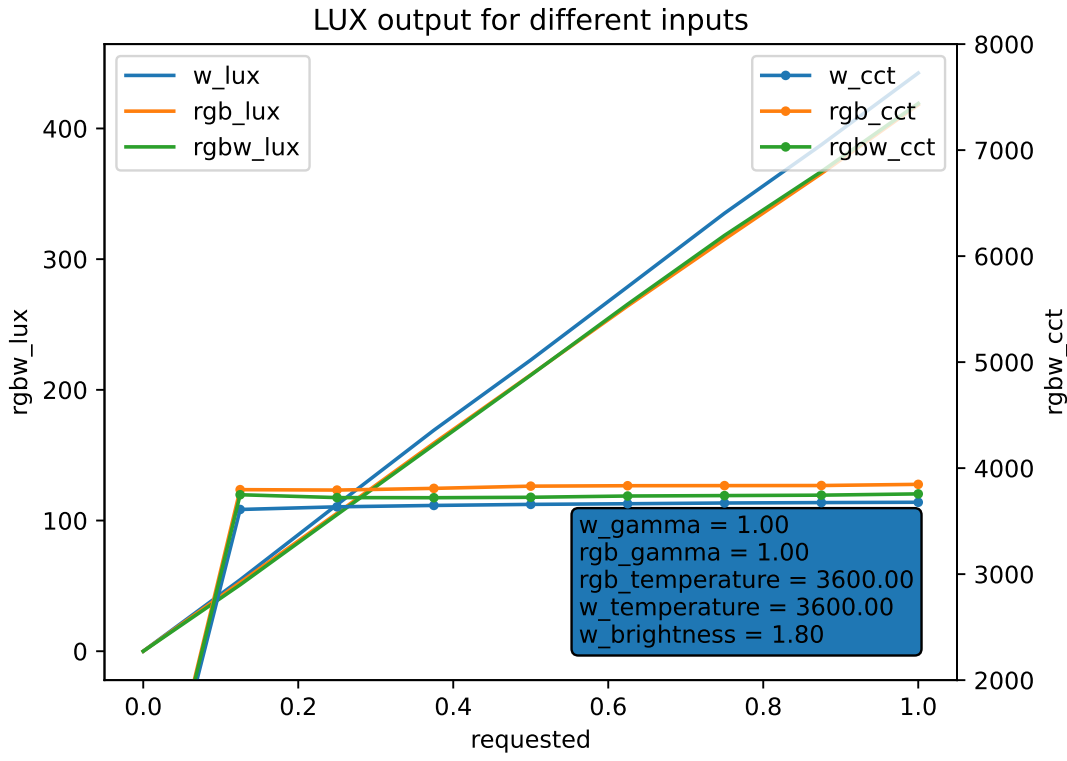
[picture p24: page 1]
requested; rgbw_lux; w_gamma = 1.00 rgb_gamma = 1.00 rgb_temperature = 3600.00 w_temperature = 3600.00 w_brightness = 1.80; w_lux rgb_lux rgbw_lux; rgbw_cct; w_cct rgb_cct rgbw_cct

LUX output for different inputs

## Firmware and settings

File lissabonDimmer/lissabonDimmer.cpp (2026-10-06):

//
// A dimmer server, which allows controling a PWM (pulse-width modulation)
// DC dimmer.
//

#include "iotsa.h"
#include "iotsaLed.h"
#include "iotsaConfigFile.h"
#include "PWMDimmer.h"
#include "DimmerUI.h"

//
// Device can be rebooted or configuration mode can be requested by quickly tapping any button.
// TAP_DURATION sets the maximum time between press-release-press-etc.
#define TAP_COUNT_MODE_CHANGE 4
#define TAP_COUNT_REBOOT 8
#define TAP_DURATION 1000

IotsaApplication application("Lissabon Dimmer");

#ifdef IOTSA_WITH_BLE
#else
#warning Building this module without BLE support may be a bit pointless
#endif

#include "iotsaBattery.h"
#include "iotsaRunmode.h"
#define PIN_DISABLESLEEP 0
//#define PIN_VBAT 37
//#define VBAT_100_PERCENT (12.0/11.0) // 100K and 1M resistors divide by 11, not 10...
IotsaBatteryMod batteryMod(application);

#include "iotsaInput.h"

#include VARIANT

#ifdef WITH_UI
IotsaInputMod inputMod(application, inputs, sizeof(inputs)/sizeof(inputs[0]));
#endif

#include "DimmerBLEServer.h"

using namespace Lissabon;

//
// PWM Lighting module. 
//

class LissabonDimmerMod : public IotsaModule, public DimmerCallbacks {
public:
  LissabonDimmerMod(IotsaApplication& _app)
  : IotsaModule(_app),
    dimmer(1, PIN_PWM_DIMMER, CHANNEL_PWM_DIMMER, this),
#ifdef WITH_UI
    dimmerUI(dimmer),
#endif
#ifdef WITH_DOUBLE_DIMMER
    dimmer2(2, PIN_PWM_DIMMER_2, CHANNEL_PWM_DIMMER_2, this),
#ifdef WITH_UI
    dimmerUI2(dimmer2),
#endif
#endif
    dimmerBLEServer(dimmer)
  {
  }
  void setup();
  void lateSetup() override;
  String info();
  void configLoad();
  void configSave();
  void loop();

protected:
  void dimmerOnOffChanged() override;
  void dimmerValueChanged() override;
  void dimmerAvailableChanged() override {};
  void webHandler() override;
  bool getHandler(const char *path, JsonObject& reply) override;
  bool putHandler(const char *path, const JsonVariant& request, JsonObject& reply) override;

private:
  PWMDimmer dimmer;
#ifdef WITH_DOUBLE_DIMMER
  PWMDimmer dimmer2;
#endif
#ifdef WITH_UI
  DimmerUI dimmerUI;
#ifdef WITH_DOUBLE_DIMMER
  DimmerUI dimmerUI2;
#endif
#endif
  DimmerBLEServer dimmerBLEServer;
  uint32_t saveAtMillis = 0;
  uint32_t lastButtonChangeMillis = 0;
  int buttonChangeCount = 0;
};

void LissabonDimmerMod::dimmerOnOffChanged() {
  // Called whenever any button changed state.
  // Used to give visual feedback (led turning off) on presses and releases,
  // and to enable config mod after 4 taps and reboot after 8 taps
  uint32_t now = millis();
  if (lastButtonChangeMillis > 0 && now < lastButtonChangeMillis + TAP_DURATION) {
    // A button change that was quick enough for a tap
    lastButtonChangeMillis = now;
    buttonChangeCount++;
    if (buttonChangeCount == TAP_COUNT_MODE_CHANGE) {
      IFDEBUG IotsaSerial.println("tap mode change");
      iotsaController.allowRequestedConfigurationMode();
    }
    if (buttonChangeCount == TAP_COUNT_REBOOT) {
      IFDEBUG IotsaSerial.println("tap mode reboot");
      iotsaController.requestReboot(1000);
    }
  } else {
    // Either the first change, or too late. Reset.
    lastButtonChangeMillis = millis();
    buttonChangeCount = 0;
  }
}

void
LissabonDimmerMod::webHandler() {
  IotsaWebServer *server = api.webService->server;
  bool anyChanged = false;
  anyChanged |= dimmer.formHandler_args(server, "dimmer", true);
#ifdef WITH_DOUBLE_DIMMER
  anyChanged |= dimmer2.formHandler_args(server, "dimmer2", true);
#endif
  if (anyChanged) {
    configSave();
    dimmer.updateDimmer();
  }
  
  String message = "<html><head><title>Dimmer</title></head><body><h1>Dimmer</h1>";
  message += "<h2>Settings</h2><form method='post'>";
  dimmer.formHandler_fields(message, "dimmer", "dimmer", false);
  message += "<input type='submit' name='set' value='Set Dimmer'></form>";
#ifdef WITH_DOUBLE_DIMMER
  message += "<form method='post'>";
  dimmer2.formHandler_fields(message, "dimmer2", "dimmer2", false);
  message += "<input type='submit' name='set' value='Set Dimmer'></form>";
#endif
  message += "<h2>Configuration</h2><form method='post'>";
  dimmer.formHandler_fields(message, "dimmer", "dimmer", true);
  message += "<input type='submit' name='set' value='Update Configuration'></form>";
#ifdef WITH_DOUBLE_DIMMER
  message += "<form method='post'>";
  dimmer2.formHandler_fields(message, "dimmer2", "dimmer2", true);
  message += "<input type='submit' name='set' value='Update Configuration'></form>";
#endif
  message += "</body></html>";
  server->send(200, "text/html", message);
}

String LissabonDimmerMod::info() {
  // Return some information about this module, for the main page of the web server.
  String message = "<p>";
  message += dimmer.info();
  message += "See <a href=\"/dimmer\">/dimmer</a> for setting the light level.";
#ifdef IOTSA_WITH_REST
  message += " Or use REST api at <a href='/api/dimmer'>/api/dimmer</a>.";
#endif
#ifdef IOTSA_WITH_BLE
  message += " Or use BLE service " + String(Lissabon::serviceUUIDstring) + ".";
#endif
  message += "</p>";
  return message;
}

bool LissabonDimmerMod::getHandler(const char *path, JsonObject& reply) {
  dimmer.getHandler(reply);
#ifdef WITH_DOUBLE_DIMMER
  JsonObject dimmer2Reply = reply["dimmer2"].to<JsonObject>();
  dimmer2.getHandler(dimmer2Reply);
#endif
  return true;
}

bool LissabonDimmerMod::putHandler(const char *path, const JsonVariant& request, JsonObject& reply) {
  bool anyChanged = false;
  bool dimmerChanged = false;
  JsonObject reqObj = request.as<JsonObject>();
  if (!reqObj) return false;
  if (dimmer.putHandler(reqObj)) anyChanged = dimmerChanged = true;
  if (dimmerChanged) dimmer.updateDimmer(); // xxxjack or is this called already?
#ifdef WITH_DOUBLE_DIMMER
  bool dimmer2Changed = false;
  JsonVariant dimmer2Request = reqObj["dimmer2"];
  if (dimmer2Request) {
    if (dimmer2.putHandler(dimmer2Request)) anyChanged = dimmer2Changed = true;
  }
  if (dimmer2Changed) dimmer2.updateDimmer();
#endif
  if (anyChanged) {
    // Should do this only for config changes
    configSave();
  }
  return anyChanged;

}

void LissabonDimmerMod::lateSetup() {
  name = "dimmer";
  // /dimmer (the module page, GET + POST) is registered by this get=true
  // api.setup(); it dispatches to webHandler().
  api.setup("dimmer", true, true);
}

void LissabonDimmerMod::configLoad() {
  IotsaConfigFileLoad cf("/config/pwmdimmer.cfg");
  dimmer.configLoad(cf, "dimmer");
#ifdef TOGGLE_ONOFF_ON_REBOOT
  // Save the toggled on/off state
  dimmer.isOn = !dimmer.isOn;
  IFDEBUG IotsaSerial.printf("Saving toggled isOn state: %d\n", dimmer.isOn);
  configSave();
#endif
#ifdef WITH_DOUBLE_DIMMER
  dimmer2.configLoad(cf, "dimmer2");
#endif
}

void LissabonDimmerMod::configSave() {
  IotsaConfigFileSave cf("/config/pwmdimmer.cfg");
  dimmer.configSave(cf, "dimmer");
#ifdef WITH_DOUBLE_DIMMER
  dimmer2.configSave(cf, "dimmer2");
#endif

}

void LissabonDimmerMod::setup() {
  // Allow switching the dimmer to iotsa config mode over BLE or with taps
  batteryMod.allowBLEConfigModeSwitch();
#ifdef IOTSA_WITH_BLE
  // Wires this appliance's identify (blink) into the generic core runmode
  // BLE identify command, so DimmerBLEClient's identify() -- which now goes
  // through IotsaRunmodeBLEClient, not Lissabon's own identifyUUID -- has
  // something to actually trigger here. A double dimmer flashes both
  // channels: it's the device that's asked to show itself (a single channel
  // can still be identified through its own REST/web identify field).
  if (IotsaRunmodeMod::instance()) IotsaRunmodeMod::instance()->addIdentifyCallback([this]() {
    dimmer.identify();
#ifdef WITH_DOUBLE_DIMMER
    dimmer2.identify();
#endif
  });
#endif
  // Set pins for measuring battery voltage and disabling sleep.
#ifdef PIN_VBAT
  batteryMod.setPinVBat(PIN_VBAT, VBAT_100_PERCENT);
#endif
#ifdef PIN_DISABLESLEEP
  batteryMod.setPinDisableSleep(PIN_DISABLESLEEP);
#endif
  configLoad();
#if defined(WITH_TOUCHPADS)
  iotsaController.allowRCMDescription("tap any touchpad 4 times");
  dimmerUI.setUpDownButtons(encoder);
#elif defined(WITH_BUTTONS)
  iotsaController.allowRCMDescription("press button 4 times");
  dimmerUI.setUpDownButtons(encoder);
#elif defined(WITH_1BUTTON)
  iotsaController.allowRCMDescription("press button 4 times");
  dimmerUI.setCyclingButton(encoder);
#ifdef WITH_DOUBLE_DIMMER
  dimmerUI2.setCyclingButton(encoder2);
#endif
#elif defined(WITH_ROTARY)
  iotsaController.allowRCMDescription("press button 4 times");
  dimmerUI.setRotaryEncoder(button, encoder);
#endif
  dimmer.setup();
  dimmerBLEServer.setup();
  dimmer.updateDimmer();
#ifdef WITH_DOUBLE_DIMMER
  dimmer2.setup();
  dimmerBLEServer.setAuxDimmer(&dimmer2);
  dimmer2.updateDimmer();
#endif
}

void LissabonDimmerMod::loop() {
  // See if we have a value to save (because the user has been turning the dimmer)
  if (saveAtMillis > 0 && millis() > saveAtMillis) {
    saveAtMillis = 0;
    configSave();
  }
  dimmer.loop();
#ifdef WITH_DOUBLE_DIMMER
  dimmer2.loop();
#endif
}

void LissabonDimmerMod::dimmerValueChanged() {
  iotsaController.postponeSleep(2000);
  saveAtMillis = millis() + 1000;
  configSave();
}
// Instantiate the Led module, and install it in the framework
LissabonDimmerMod dimmerMod(application);

// Standard setup() method, hands off most work to the application framework
void setup(void){
  application.setup();
  application.lateSetup();
}

// Standard loop() routine, hands off most work to the application framework
void loop(void){
  application.loop();
}

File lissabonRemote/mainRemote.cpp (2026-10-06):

//
// A Neopixel strip server, which allows control over a strip of neopixels, intended
// to be used as lighting. Color can be set as fraction RGB or HSL, gamma can be changed,
// interval between lit pixels can be changed. Control is through a web UI or
// through REST calls (and/or, depending on Iotsa compile time options, COAP calls).
// The web interface can be disabled by building iotsa with IOTSA_WITHOUT_WEB.
//

#include "iotsa.h"
#include "iotsaLed.h"
#include "iotsaConfigFile.h"
#include <set>

#undef DEBUG_PRINT_HEAP_SPACE

#define LED_PIN 22  // Define to turn on the LED when powered and not sleeping.

//
// Device can be rebooted or configuration mode can be requested by quickly tapping any button.
// TAP_DURATION sets the maximum time between press-release-press-etc.
#define TAP_COUNT_MODE_CHANGE 4
#define TAP_COUNT_REBOOT 8
#define TAP_DURATION 1000

IotsaApplication application("Lissabon Remote");

#include "iotsaBattery.h"
#define PIN_DISABLESLEEP 0
#define PIN_VBAT 37
#define VBAT_100_PERCENT (12.0/11.0) // 100K and 1M resistors divide by 11, not 10...
IotsaBatteryMod batteryMod(application);

#include "iotsaInput.h"
Touchpad touch1down(32, true, true, true);
Touchpad touch1up(13, true, true, true);
UpDownButtons encoder1(touch1down, touch1up, true);
#ifdef WITH_SECOND_DIMMER
Touchpad touch2down(14, true, true, true);
Touchpad touch2up(15, true, true, true);
UpDownButtons encoder2(touch2down, touch2up, true);
#endif // WITH_SECOND_DIMMER

Input* inputs[] = {
  &encoder1,
#ifdef WITH_SECOND_DIMMER
  &encoder2,
#endif
};

IotsaInputMod touchMod(application, inputs, sizeof(inputs)/sizeof(inputs[0]));

#include "iotsaBLEClientCollection.h"

#include "DimmerCollection.h"
#include "DimmerBLEClient.h"
#include "DimmerUI.h"

using namespace Lissabon;

class LissabonRemoteMod : public IotsaBLEClientCollectionMod, public DimmerCallbacks {
public:
  LissabonRemoteMod(IotsaApplication &_app)
  : IotsaBLEClientCollectionMod(_app)
  {
    DimmerBLEClient *dimmer = new DimmerBLEClient(1, *this, this);
    dimmer->followDimmerChanges(true);
    dimmers.push_back(dimmer);
  #ifdef WITH_SECOND_DIMMER
    dimmer = new DimmerBLEClient(2, *this, this);
    dimmer->followDimmerChanges(true);
    dimmers.push_back(dimmer);
  #endif
  }
  void setup() override;
  void lateSetup() override;
  String info() override;
  void configLoad() override;
  void configSave() override;
  void loop() override;
  // Fixed set of dimmers (constructed above): no adding or removing by name
  // through the base class's REST/web (cwi-dis/iotsa#264). Renaming a dimmer
  // still works through its own fields.
  bool addDeviceByName(const std::string& name) override { return false; }
  bool removeDeviceByName(const std::string& name) override { return false; }

protected:
  bool getHandler(const char *path, JsonObject& reply) override;
  bool putHandler(const char *path, const JsonVariant& request, JsonObject& reply) override;
  void unknownDimmerBLEClientFound(const NimBLEAdvertisedDevice& deviceAdvertisement);
  // Only surface other lissabon BLE devices as "unknown/addable" candidates
  // (cwi-dis/iotsa#264).
  bool isInterestingUnknownDevice(const NimBLEAdvertisedDevice* device) override {
    return device->isAdvertisingService(Lissabon::serviceUUID);
  }
private:
  void dimmerOnOffChanged() override;
  void dimmerValueChanged() override;
  void dimmerAvailableChanged() override {};
  void webHandler() override;
  void ledOn();
  void ledOff();
  DimmerCollection dimmers;
  std::vector<DimmerUI*> dimmerUIs;
  uint32_t saveAtMillis = 0;
  uint32_t ledOffUntilMillis = 0;
  uint32_t lastButtonChangeMillis = 0;
  int buttonChangeCount = 0;
};

void LissabonRemoteMod::ledOn() {
#ifdef LED_PIN
  digitalWrite(LED_PIN, LOW);
#endif
}

void LissabonRemoteMod::ledOff() {
#ifdef LED_PIN
  digitalWrite(LED_PIN, HIGH);
#endif
  
}

void LissabonRemoteMod::dimmerOnOffChanged() {
  // Called whenever any button changed state.
  // Used to give visual feedback (led turning off) on presses and releases,
  // and to enable config mod after 4 taps and reboot after 8 taps
  uint32_t now = millis();
  ledOn();
  if (lastButtonChangeMillis > 0 && now < lastButtonChangeMillis + TAP_DURATION) {
    // A button change that was quick enough for a tap
    lastButtonChangeMillis = now;
    buttonChangeCount++;
    IFDEBUG IotsaSerial.printf("tap mode count=%d\n", buttonChangeCount);
    if (buttonChangeCount == TAP_COUNT_MODE_CHANGE) {
      IFDEBUG IotsaSerial.println("tap mode change");
      iotsaController.allowRequestedConfigurationMode();
    }
    if (buttonChangeCount == TAP_COUNT_REBOOT) {
      IFDEBUG IotsaSerial.println("tap mode reboot");
      ledOffUntilMillis = now + 2000;
      iotsaController.requestReboot(1000);
    }
  } else {
    // Either the first change, or too late. Reset.
    lastButtonChangeMillis = millis();
    buttonChangeCount = 0;
    IFDEBUG IotsaSerial.println("tap mode 0");
  }
}
void
LissabonRemoteMod::webHandler() {
  IotsaWebServer *server = api.webService->server;
  bool anyChanged = false;
  // xxxjack this also saves the config file if a non-config setting has been changed. Oh well...
  anyChanged |= dimmers.formHandler_args(server, "", true);
  anyChanged |= IotsaBLEClientCollectionMod::formHandler_args(server, "", true);
  if (anyChanged) {
    configSave();
  }
  String message = "<html><head><title>BLE Dimmers</title></head><body><h1>BLE Dimmers</h1>";
  message += "<h2>Dimmer Settings</h2><form method='post'>";
  dimmers.formHandler_fields(message, "", "", false);
  message += "<input type='submit' name='set' value='Set Dimmers'></form><br>";

  message += "<h2>Dimmer Configuration</h2><form method='post'>";
  dimmers.formHandler_fields(message, "", "", true);
  message += "<input type='submit' name='config' value='Configure Dimmers'></form><br>";

  IotsaBLEClientCollectionMod::formHandler_fields(message, "BLE Dimmer", "dimmer", true);

  message += "</body></html>";
  server->send(200, "text/html", message);
}

String LissabonRemoteMod::info() {

  String message = "<p>";
  message += dimmers.info();
  message += "See <a href='/bledimmer'>/bledimmer</a> to change settings or <a href='/api/bledimmer'>/api/bledimmer</a> for REST API.<br>";
  message += "</p>";
  return message;
}

bool LissabonRemoteMod::getHandler(const char *path, JsonObject& reply) {
  // xxxjack need to distinguish between config and operational parameters
  IotsaBLEClientCollectionMod::getHandler(path, reply);
  dimmers.getHandler(reply);
  return true;
}

bool LissabonRemoteMod::putHandler(const char *path, const JsonVariant& request, JsonObject& reply) {
  // xxxjack need to distinguish between config and operational parameters
  bool anyChanged = false;
  anyChanged = IotsaBLEClientCollectionMod::putHandler(path, request, reply);
  anyChanged |= dimmers.putHandler(request);
  if (anyChanged) {
    configSave();
  }
  return anyChanged;
}
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

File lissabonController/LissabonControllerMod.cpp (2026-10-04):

#include "LissabonControllerMod.h"

using namespace Lissabon;

Display *display;

#define LOG_BLE if(0)
#define LOG_UI if(1)

void
LissabonControllerMod::setDimmerFollowed(int index, bool follow) {
  // Only the selected dimmer ever gets a live, maintained BLE connection
  // (cwi-dis/lissabon#31) -- background-syncing all of them at once is what
  // made the shared NIMBLE_MAX_CONNECTIONS pool genuinely scarce. Living
  // dangerously: no RTTI, but the factory only ever creates DimmerBLEClients.
  if (index < 0 || index >= dimmers.size()) return;
  DimmerBLEClient* d = reinterpret_cast<DimmerBLEClient*>(dimmers.at(index));
  d->followDimmerChanges(follow);
}

void
LissabonControllerMod::selectDimmer(bool next, bool prev) {
  int oldSelectedDimmerIndex = selectedDimmerIndex;
  if (next) {
    selectedDimmerIndex++;
    selectedDimmerIsAvailable = false;
  }
  if (prev) {
    selectedDimmerIndex--;
    selectedDimmerIsAvailable = false;
  }
  if (selectedDimmerIndex < 0) {
    display->flash();
    selectedDimmerIndex = 0;
  }
  if (selectedDimmerIndex >= dimmers.size()) {
    display->flash();
    selectedDimmerIndex = dimmers.size()-1;
  }
  // Missing since this save mechanism was introduced (a535ca3, 2023): setLevel()/
  // toggle() both mark saveNeeded when they change selectedDimmerIndex's saved value,
  // but selectDimmer() itself -- the rocker switch, the actual way the selection
  // normally changes -- never did, so scrolling to a different strip without also
  // touching its level/on-off was silently never persisted.
  if (selectedDimmerIndex != savedSelectedDimmerIndex) saveNeeded = true;
  // Move the live connection to the new selection -- only on a genuine change,
  // not the internal (false, false) refresh-only calls dimmerAvailableChanged()
  // makes on every state change (those fire constantly during connect/fail/retry
  // churn). Gating on the index actually changing, rather than next||prev,
  // also handles the "next at the last dimmer" clamp case correctly -- next
  // can be true with no real change, and toggling follow off-then-on on the
  // same dimmer would force a pointless resync (same bug class as the
  // nudge/sleep-postpone fixes below: observed live, 2026-09-26, that an
  // unconditional per-call side effect here turns into a permanent lock or a
  // constant reset).
  if (selectedDimmerIndex != oldSelectedDimmerIndex) {
    setDimmerFollowed(oldSelectedDimmerIndex, false);
    setDimmerFollowed(selectedDimmerIndex, true);
  }
  LOG_UI IotsaSerial.printf("LissabonController: now selectedDimmer=%d\n", selectedDimmerIndex);
  updateDisplay(false);
  buttons.refreshEncoder();
  // Same bug class as the nudge fix above: only on a genuine rocker-driven
  // change, not dimmerAvailableChanged()'s internal (false, false) calls --
  // those fire constantly during connect/fail/retry churn, and
  // postponeSleep(4000) adds activityExtraWakeDuration on top (see
  // IotsaSleepPolicy::postponeSleep()), so unconditionally calling it here
  // meant the sleep-inhibit deadline got pushed out by a full minute on
  // every single internal refresh -- confirmed live, 2026-09-26: control
  // hadn't slept in 7 hours, with postponeSleep sitting at ~64000ms
  // (4000 + activityExtraWakeDuration) essentially continuously.
  if (next || prev) iotsaController.postponeSleep(4000);
  if (selectedDimmerIndex < dimmers.size()) {
    auto d = dimmers.at(selectedDimmerIndex);
    bool availableNow = d->available();
    bool mustUpdate = availableNow && !selectedDimmerIsAvailable;
    selectedDimmerIsAvailable = availableNow;
    if (mustUpdate) {
      LOG_UI IotsaSerial.printf("LissabonController: refresh selectedDimmer=%d\n", selectedDimmerIndex);
      d->refresh();
    }
  }
}

float LissabonControllerMod::getTemperature() {
#ifdef DIMMER_WITH_TEMPERATURE
  auto d = getDimmerForCommand(selectedDimmerIndex);
  if (d) {
    float rv = (d->temperature - DIMMER_MIN_TEMPERATURE) / (DIMMER_MAX_TEMPERATURE - DIMMER_MIN_TEMPERATURE);
    if (rv < 0) rv = 0;
    if (rv > 1) rv = 1;
    return rv;
  }
#endif
  return 0;
}

void LissabonControllerMod::setTemperature(float temperature) {
#ifdef DIMMER_WITH_TEMPERATURE
  auto d = getDimmerForCommand(selectedDimmerIndex);
  if (d == nullptr) {
    display->flash();
    return;
  }
  float tempKelvin = DIMMER_MIN_TEMPERATURE + temperature * (DIMMER_MAX_TEMPERATURE-DIMMER_MIN_TEMPERATURE);
  if (tempKelvin < DIMMER_MIN_TEMPERATURE) tempKelvin = DIMMER_MIN_TEMPERATURE;
  if (tempKelvin > DIMMER_MAX_TEMPERATURE) tempKelvin = DIMMER_MAX_TEMPERATURE;
  d->temperature = tempKelvin;
  d->updateDimmer();
  updateDisplay(false);
  LOG_UI IotsaSerial.printf("LissabonController: updated dimmer %d temperature %f\n", selectedDimmerIndex, temperature);
  iotsaController.postponeSleep(4000);
#else
  display->flash();
#endif
}

float LissabonControllerMod::getLevel() {
  auto d = getDimmerForCommand(selectedDimmerIndex);
  if (d) return d->level;
  return 0;
}

void LissabonControllerMod::setLevel(float level) {
  auto d = getDimmerForCommand(selectedDimmerIndex);
  if (d == nullptr) {
    display->flash();
    return;
  }
  d->level = level;
  d->updateDimmer();
  updateDisplay(false);
  LOG_UI IotsaSerial.printf("LissabonController: updated dimmer %d level %f\n", selectedDimmerIndex, level);
  if (selectedDimmerIndex != savedSelectedDimmerIndex) saveNeeded = true;
  iotsaController.postponeSleep(4000);
}

void LissabonControllerMod::toggle() {
  auto d = getDimmerForCommand(selectedDimmerIndex);
  if (d != nullptr) {
    d->isOn = !d->isOn;
    d->updateDimmer();
    updateDisplay(false);
    if (selectedDimmerIndex != savedSelectedDimmerIndex) saveNeeded = true;
  }
}
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

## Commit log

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2019-12-29 Various fixes for rgbw pixelstrips
    [iotsaPixelstrip.cpp]
2019-12-29 Added BLE interface, and fixed temp/illum saving and loading
    [iotsaPixelstrip.cpp]
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2020-01-01 Added debouncing code to touch sensors, which is actually to cater for 50Hz interference
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2020-01-02 Fixed battery measurement (1:10 resistor bridge is divide by 11, not divide by 10:-)
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2020-01-20 Using binding to get rotary encoder and button value, and save values to config file
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2020-04-19 Modified schematic to use Pololu 3v3 regulator (onboard 3v3 regulator dissipated too much)
    [hardware.fzz]
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2020-05-04 Added debug prints and other code to find disconnect() crash. Found it, double free in BLE stack. Created issue https://github.com/espressif/arduino-esp32/issues/3966
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2020-05-26 Fixed typos, and build minimal and maximal example
    [AbstractDimmer.cpp]
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2020-05-28 Fixed various issues with parameters
    [AbstractDimmer.cpp]
2020-05-28 Added handling of white LED brightness/temperature, and fixed various bugs
    [LedstripDimmer.cpp, lissabonLedstrip.cpp]
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2020-05-29 Fixed keeping dimmer state over reboots (missed save)
    [AbstractDimmer.cpp, DimmerUI.cpp]
2020-05-29 Experimenting with normal and error functions for focus
    [LedstripDimmer.cpp]
2020-05-30 New way of using normal and error functions
    [LedstripDimmer.cpp]
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2020-05-31 Created remote switch example. Really mainly so I can run it on esp32thing under minimodule debugger and find the problem with BLE re-connect.
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2021-04-07 Use GPIO26 in stead of GPIO12. The latter is used at boot to determine flash voltage, so let's hope this fixes the failing boards issue.
    [Hardware-12v.fzz, Hardware-5v.fzz]
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2021-04-11 NPB library crashes when specifying <2 neopixels on esp32. Work around this.
    [iotsaPixelstrip.cpp]
2021-04-15 GPIO2 doesn't work as touchpad either on the pico. Use 32.
    [lissabonLedstrip.cpp]
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2021-04-24 Various fixes to DimmerCollection interface
    [AbstractDimmer.cpp]
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2021-05-11 Playing with power consumption of strips while off, and flashing first LED. Strips are still using 10-15mA during 200mS wake periods during light sleep, leaked DATA-5V. But flashing is much less obvi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
    [iotsaPixelstrip.cpp]
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2021-07-28 Fixed various issues with dimmer configuration. Also tried to fix missing dimmers causing continuous scan, but with less success.
    [AbstractDimmer.cpp]
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2021-08-01 Fixed config/settings UI updates
    [lissabonDimmer.cpp]
2021-08-01 Fixed web UI for ledstrips
    [LedstripDimmer.cpp, lissabonLedstrip.cpp]
2021-08-11 Adapted for fixed NeiPixelBus that floats the control pin when the strip is deleted. Don't merge until a new NPB release is done.
    [iotsaPixelstrip.cpp]
2022-06-29 BLE control logic was wrong: values were not forwarded to the dimmers. Fixed.
    [DimmerBLEServer.cpp]
2022-07-14 Clarifying log output to try and find issue with BLE dimmers not working as expected
    [AbstractDimmer.cpp]
2022-07-14 BLE dimmers are starting to work. Problem was preposterous minLevel value
    [AbstractDimmer.h]
2022-07-19 Fixed animation problem: we were using gamma-corrected level as the starting point. Use uncorrected.
    [AbstractDimmer.cpp, AbstractDimmer.h, PWMDimmer.cpp]
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2022-07-25 overrideLevel is gone. For now work around this by disabling the clamping to correct color temperature.
    [LedstripDimmer.cpp]
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2022-08-05 Allow using uniform light by setting focalSpread=0. Fixed bug in form.
    [LedstripDimmer.cpp]
2022-08-05 It seems the | construction does not work for ArduinoJson::JsonVariant for float numbers. Use containsKey.
    [LedstripDimmer.cpp]
2022-08-05 Undid previous change: problem was with iotsaControl. Pass calibrationMode in API.
    [LedstripDimmer.cpp]
2022-08-05 Fixed calibrationMode brightness level
    [LedstripDimmer.cpp]
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2022-08-14 Fixed some issues with calibration mode
    [LedstripDimmer.cpp]
2022-08-14 Fixing cct plots, also adapting for changes to colourscience (I think)
    [striprechts-cct.csv, striprechts-lux-daylight.csv, striprechts-lux-rgb3600.csv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]
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2022-08-15 Attempting to do RGBW CCT measurements. Not working yet.
    [striprechts-cct.csv]
2022-08-16 Changed measurement names. Trying to fix lux/cct measurements to give same results but failing.
    [striprechts-cct.csv, striprechts-lux-rgb3600.csv]
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2023-04-16 Logic was broken without IOTSA_NPB_POWER_PIN. Fixed.
    [iotsaPixelstrip.cpp]
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2023-04-23 For some reason the data pin wasn't floated when deleting the ledstrip (I thought that was fixed in NPB?). Setting it as an input ourselves.
    [iotsaPixelstrip.cpp]
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2023-04-23 Fixed tap-to-mode to 3 taps, tap-to-reboot to 6. Removed some debug output.
    [LedstripDimmer.cpp, iotsaPixelstrip.cpp, lissabonLedstrip.cpp]
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2023-04-27 Bug fixes to buttons, and grey out unavailable dimmers in display by clearing pixels
    [buttons.cpp]
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2023-04-28 Fixed rotary encoder issue.
    [buttons.cpp]
2023-05-05 Fixed various issues with button and BLE handling
    [buttons.cpp]
2023-05-05 Fixed various issues with temperature handling
    [AbstractDimmer.h, DimmerBLEServer.cpp, DimmerUI.cpp]
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2023-05-05 Don't clamp the level depending on maximum correct tempersture level: that happens later, when computing the per-pixel values.
    [LedstripDimmer.cpp]
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2023-05-07 Show mode change and reboot
    [buttons.cpp]
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2023-05-21 Implemented using a task to connect to the dimmers. `implementation has a bug: scanning stops too soon.
    [2-striprechts-lux.csv, 3-striprechts-lux-native.csv, 3-striprechts-lux.csv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]
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2023-05-28 Fixed wakeup with main pushbutton. Dim led display when sleeping.
    [buttons.cpp]
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2024-12-26 Added a 1-button dimmer (short press is toggle on/off, long press cycles through intensities).
    [DimmerUI.cpp, lissabonDimmer.cpp]
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2024-12-27 Fixed second dimmer operation.
    [PWMDimmer.cpp, lissabonDimmer.cpp]
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2025-12-26 Fixes so that dimmers without DIMMER_WITH_LEVEL (so switches, really) work as expected.
    [AbstractDimmer.cpp, DimmerBLEServer.cpp]
2025-12-26 New dimmer type candle: no switches except reset, can only turn on/off, will change on/off state at every reboot.
    [lissabonDimmer.cpp]
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2026-06-27 Pin lissabonLedstrip to espressif32@6.9.0; 7.x is a breaking change.
    See iotsa#112 for the migration tracking issue.
2026-06-27 Add deployed device inventory and 5V/12V safety note
    - CLAUDE.md: add deployed-devices table for all 10 lissabon devices
    at Tuinpark Lissabon, including board, strip type, pixel count,
    and notes on the reversed connector safety measure for 12V hardware
    - lissabonLedstrip/readme.md: add construction section explaining 5V vs
    12V firmware variants (NeoGrbwFeature vs NeoRgbwFeature) and the
    reversed connector convention to prevent accidental 5V/12V mix-up
2026-07-05 Increase NimBLE host task stack size to fix HPS PUT panic
    Add -DCONFIG_BT_NIMBLE_HOST_TASK_STACK_SIZE=8192 to all BLE-enabled
    appliance build flags. The NimBLE host task's default 4KB stack overflows
    when a HPS PUT request triggers JSON parsing + LittleFS write + CPU
    frequency change, causing a stack canary panic and BLE disconnect.
    Doubling the stack size eliminates the panic and makes HPS restore
    fully functional for BLE-only (wifiDisabledOnBoot) devices.
    See cwi-dis/iotsa#127 for root cause analysis and long-term fix.
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2026-07-16 Fix two config-persistence bugs in the dynamic dimmer collection
    DimmerDynamicCollection::configLoad/configSave read and wrote the
    n_dimmer count under an empty-string key instead of the computed
    ident, so the persisted dimmer count was never actually saved or
    loaded correctly across reboots.
    DimmerCollection::getHandler used .as<JsonObject>() to build each
    per-dimmer reply sub-object; under ArduinoJson v7 that only casts an
    existing value and never creates one, so the JSON REST API silently
    omitted all configured dimmers even though they existed correctly
    in memory (visible via the HTML UI and serial log). Switched to
    .to<JsonObject>(), matching the idiom used everywhere else in iotsa's
    ow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
2026-07-18 Fix stale sleep/wake duration numbers in docs
    Both said sleep/wake numbers that don't match the real deployed
    config, verified 2026-07-19 against lissabon-config/*/battery.json
    (sleepDuration=1500, wakeDuration=300 on every ledstrip/dimmer):
    - CLAUDE.md's device table said "light sleep 1200 s / 80 ms wake" --
    off by roughly three orders of magnitude on the sleep side.
    - doc/ble-power.md's measurement writeup used sleepDuration=800/
    wakeDuration=80, which is real (that's what the historical
    striphome bench measurement actually used and the graphs actually
    show), but nothing said this wasn't the current fleet default.
    Added a note pointing at the real numbers instead of rewriting th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
2026-07-18 Rename IOTSA_BLEDIMMER_CONNECT_TIMEOUT to a correctly-named class member
    Moved from a BLEDimmer.cpp file-scope constant to a proper BLEDimmer
    member (discoveryTimeoutMillis), matching the codebase's Millis-suffix
    convention. Also fixes a misleading name: despite "CONNECT_TIMEOUT",
    this has nothing to do with the connect() call -- it only gates
    connectionTask()'s discovery-wait branch (how long to keep a pending
    command alive while the device's address is still unknown).
    Deliberately not made configurable -- see cwi-dis/iotsa#144, which
    proposes moving this (and the rest of connectionTask()'s generic
    connection-lifecycle orchestration) into iotsa core. Making it a
    properly-named member now,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
2026-07-19 Rename discoveryTimeoutMillis/keepOpenMillis to user-oriented names
    discoveryTimeoutMillis -> unreachableGiveUpMillis: names the practical
    consequence (giving up because the device seems unreachable) rather
    than the internal mechanism (discovery). Also documents the assumption
    this relies on -- that it's comfortably above any live device's real
    sleep/wake cadence, which BLE itself doesn't cap, so this is only
    "basically never fires" given today's fleet's tight 1.8s cycle, not a
    protocol guarantee.
    keepOpenMillis -> stayConnectedMillis (including the constructor
    parameter and mainLedstripController.cpp's seeding variable): names
    what it's for (staying connected for a likely follow-up command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
2026-07-21 Fix code-structure issues found in #149 bullet-2 review
    - Fix ArduinoJson v6-style createNestedArray in iotsaPixelstrip.cpp,
    inconsistent with the v7 idiom already used elsewhere in the same app
    - Remove lissabonSwitch: never covered by CI, had bit-rotted (wrong base
    class, missing pure-virtual override) and duplicates lissabonExample
    - Add CI coverage for lissabonExample, which was previously untested
    - Fix libLissabon/library.properties name typo (libLssabon -> libLissabon)
    [iotsaPixelstrip.cpp]
2026-07-21 Add lissabonSimpleLight and lissabonSimpleRemote examples
    Replacements for the retired lissabonExample/lissabonSwitch, aimed at
    being genuinely minimal: each is a standalone PlatformIO project on
    esp32dev, reusing the PRG/BOOT button (GPIO0) as the on/off pushbutton
    and the onboard LED (GPIO2) as the light itself.
    lissabonSimpleLight is a local on/off-only dimmer (no brightness level),
    toggled by the button and exposed via DimmerBLEServer; state persists
    to config regardless of how it was set (button, BLE, or REST).
    lissabonSimpleRemote uses BLEDimmer to toggle a remote dimmer (e.g.
    lissabonSimpleLight) over BLE. Its LED mirrors the remote's actual
    confirmed state (via dimmerValueChanged a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
    [lissabonSimpleLight.cpp, lissabonSimpleRemote.cpp]
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2026-07-21 Fix dimmer2 invisible to REST/backup in lissabon-double-dimmer
    LissabonDimmerMod::getHandler/putHandler only ever touched the first
    PWMDimmer channel, even though dimmer2 was fully wired into the web-form
    UI and configLoad/Save. This meant GET /api/dimmer never reported
    channel 2, PUT /api/dimmer couldn't change it, and iotsa backup/restore
    silently only covered channel 1.
    Nest dimmer2's REST representation under a "dimmer2" key, matching the
    naming already used for its web-form fields and config file entries.
    Also fixes updateDimmer() being called on the wrong dimmer (or not at
    all) depending on which channel actually changed.
    [lissabonDimmer.cpp]
2026-07-24 Call allowBLEConfigModeSwitch() in lissabonController, matching other apps
    Without this, bleConfigModeSwitchAllowed stays false forever, so every
    BLE rebootWifi=2 (the physical-access confirmation for a pending
    config/OTA mode switch) is silently rejected on control -- explains why
    BLE-triggered OTA mode requests never took effect on this device, unlike
    lissabonDimmer and lissabonLedstrip which both already call this.
2026-08-04 Remove redundant deviceNotConnectable() calls on connect failure
    IotsaBLEClientConnection::connect() now handles a failed attempt
    itself via the new needsRescan flag (cwi-dis/iotsa#172) instead of
    clearing the device's address. These two call sites were re-clearing
    the address on top of that, which is exactly the behavior #172
    determined to be wrong for light-sleep devices. Resolves the
    "xxxjack good idea?" doubt-comment at the connectionTask() site --
    no, it wasn't.
2026-08-08 Fix crash when clearing all BLE dimmers with one mid-connect
    DimmerDynamicCollection::clear() deleted live BLEDimmer objects
    directly; BLEDimmer's destructor calls vTaskDelete() on its
    connectionTask, which can be blocked inside an in-flight BLE connect
    attempt. Killing that task out from under NimBLE crashes the host
    task later when an async GAP event tries to notify the now-gone task
    (observed live: LoadProhibited panic in xTaskGenericNotify, ~5s after
    "Remove All" was used while a newly-added, flaky device was still
    mid-connect).
    Since clearing all dimmers is a rare, deliberate action, sidestep the
    live teardown entirely: persist zero dimmers directly and reboot.
    A fresh boot never const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
2026-08-12 Fix lissabonRemote build: remove stale unknownDevices.insert() call
    IotsaBLEClientMod::onResult() already records unknown devices in the
    map itself (since 5f1f52d changed unknownDevices from a set to a
    map of IotsaBLEDeviceInfo*) before invoking the callback, matching
    what lissabonController's own unknownBLEDimmerFound already documents.
    The leftover set-style insert() call no longer matched map::insert's
    signature and broke the build once iotsa develop moved past 5f1f52d.
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2026-08-14 Use real NimBLE class names instead of Arduino-BLE compat aliases (cwi-dis/iotsa#185)
    NimBLEDevice.h defines BLEDevice/BLEAdvertisedDevice/BLEUUID/BLE2904 etc.
    as #define aliases for their Nim*-prefixed real names, for source
    compatibility with the old ESP32 BLE Arduino library this repo doesn't
    use. Using the real names makes it unambiguous which BLE stack a given
    call belongs to, and avoids the class of silent semantic drift bugs the
    aliases enable (see cwi-dis/iotsa#164, root-caused to exactly this).
2026-08-14 Remove espressif32@6.9.0 pin (cwi-dis/iotsa#112)
    The pin was a workaround for espressif32 7.x's coredump-partition boot
    loop. Re-verified on real hardware (kaars, lissabon-candle, classic
    ESP32): OTA-updated to a build against espressif32@7.0.1, boots clean,
    WiFi/REST/dimmer control all functional, no boot loop. See
    cwi-dis/iotsa#112 for the full investigation (also re-tested on an
    ESP32-C3 with a from-scratch USB flash including a rebuilt bootloader).
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2026-08-30 doc: antenna near-field keep-out / twist the 12V supply pair
    Stray conductors in the ESP32 PCB antenna's near field detune it and cost
    BLE range; on deployed ledstrips 20-35dB of loss was traced to the 12V
    supply leads dressed past the antenna (WiFi unaffected). New Construction
    notes section in the top-level README with the general rule, plus a short
    cross-referencing subsection in the lissabonLedstrip and lissabonDimmer
    readmes.
    Claude-Session: https://claude.ai/code/session_01V4wz1xqXMyFM6d4dKUGwgV
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2026-08-31 Correct the lolin32 board profiles (deployed hardware)
    Every `board = lolin32` in this repo actually refers to a LOLIN32 Lite
    (the only lolin32 Jack owns) except the controller, which is a Wemos
    LOLIN32 OLED.
    - lissabonDimmer (candle), lissabonRemote, lissabonLedstrip, libLissabon:
    board = lolin32 -> lolin32_lite. Behaviourally near-identical core, but
    the full lolin32 profile's LED_BUILTIN=GPIO5 is wrong for the Lite
    (GPIO22). Tracked upstream as cwi-dis/iotsa#228.
    - lissabonController: new local [lolin32_oled] section (board =
    lolin32_lite -- the closest correct core; no PlatformIO/Arduino profile
    exists for the OLED variant, and lolin32_lite's LED_BUILTIN=GPIO22
    doesn't colli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
2026-08-31 CLAUDE.md: correct the "Boards used" table
    candle + controller were listed under `lolin32`; candle is really a
    LOLIN32 Lite and controller a Wemos LOLIN32 OLED. Matches c084d92.
    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
2026-08-31 board-defs: vendor from iotsa v3.0a2 (#224)
    Replace every appliance's hand-rolled [esp32]/[esp32c3]/[lolin32]/[pico32]/
    [esp32c3supermini] sections with the shared iotsa board catalogue:
    - vendor iotsa-board-defs.ini + iotsa-board-traits.ini verbatim from
    iotsa v3.0a2 into the repo root;
    - each appliance platformio.ini pulls them in with
    extra_configs = ../iotsa-board-*.ini and its [env:*] sections just
    'extends =' the right board (esp32dev / lolin32 / lolin32_oled /
    pico32 / esp32c3supermini), keeping only genuinely app-specific bits
    (DIMMER_* / VARIANT flags, no_ota override for the kitchen remote);
    - lissabonController drops its local [lolin32_oled] section -- iotsa now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
2026-09-04 Migrate mode/reboot/sleep calls to iotsaController.*/iotsaStatus.* (cwi-dis/iotsa#243)
    The iotsaConfig.* mode/reboot/sleep forwarders were removed in cwi-dis/iotsa#243
    (#106 had kept them one release); this was the last hard-broken repo in the
    downstream sweep. 32 call sites across 8 files, all literal renames,
    behaviour-identical:
    - postponeSleep(ms) x10 (libLissabon/src/{AbstractDimmer,BLEDimmer}.cpp,
    lissabonDimmer/{PWMDimmer,lissabonDimmer}.cpp, lissabonLedstrip/lissabonLedstrip.cpp,
    lissabonController/mainLedstripController.cpp) -> iotsaController.postponeSleep
    - allowRCMDescription(...) x7 -> iotsaController.allowRCMDescription
    - requestReboot(1000) x6 -> iotsaController.requestRe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
    [AbstractDimmer.cpp, PWMDimmer.cpp, buttons.cpp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]
2026-09-23 lissabonLedstrip: show iotsa WiFi/config/OTA status on pixel 0 (#28)
    Overlays iotsaStatus's semantic signals (override/mode/wifi) onto pixel 0
    in LedstripDimmer::loop(), restoring the real light value once the
    signal clears. IotsaPixelstripMod::keepPowered() latches the strip's
    power on through the dark phases of a blink/breathe/gap cycle, so the
    5V/12V rail doesn't get power-cycled every time the indicator blinks.
    Suppressed during calibration mode to avoid corrupting colour-sensor
    readings.
    Also: gate the leftover per-loop debug printf behind DEBUG_LEDSTRIP,
    and drop the unused iotsaLed.h include (IotsaLedMod is never
    instantiated in this repo).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
    [LedstripDimmer.cpp, iotsaPixelstrip.cpp, lissabonLedstrip.cpp]
2026-09-24 lissabonLedstrip: pulse pixel 0 white on each tap and before reboot
    Gives visual confirmation of tap-dance progress (100ms on/off blink per
    registered tap) and of the reboot trigger (500ms solid, inside the
    existing 1000ms delay before requestReboot actually fires). Mode-change
    taps need no separate pulse since a successful promote immediately shows
    its own breathe pattern via modeSignal(). Builds on the pixel-0 status
    overlay (#28, 7ebff41) — reuses its existing pulse-channel plumbing with
    no changes needed outside _tap() itself.
    [lissabonLedstrip.cpp]
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2026-09-26 Rename BLEDimmer to DimmerBLEClient
    Matches DimmerBLEServer's word order (Dimmer + BLE + role) instead of
    flipping it, and says "Client" explicitly instead of leaving the role
    to be inferred. Also shares the BLEClient suffix with the
    IotsaRunmodeBLEClient base class it's about to inherit from.
    Mechanical rename across all three consumers (lissabonController,
    lissabonRemote, lissabonSimpleRemote) plus the BLEDIMMER_DEBUG macro
    and CLAUDE.md's description. Build-verified on all three.
    [DimmerBLEClient.cpp]
2026-09-26 Fix up BLEDimmer -> DimmerBLEClient: actual content changes
    The previous commit only captured the file rename itself (a bad
    pathspec in git add silently aborted before staging any content
    changes). This carries the real diff: class name, include guard,
    BLEDIMMER_DEBUG macro, and all three consumers (lissabonController,
    lissabonRemote, lissabonSimpleRemote) plus CLAUDE.md. Build-verified
    on all three after this.
    [DimmerBLEClient.cpp, lissabonSimpleRemote.cpp, mainRemote.cpp]
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2026-09-27 DimmerBLEClient: use IotsaBLEClientDevice's new IotsaApiModObject surface
    Follows cwi-dis/iotsa#268: retarget() now does the identity-swap and
    owner-registration work setName() used to hand-roll, and configLoad/
    configSave/putHandler/formHandler_TD/formHandler_args gain the disambiguating
    overrides needed now that IotsaBLEClientDevice, not just AbstractDimmer,
    declares them. AbstractDimmer's own name field is still assigned separately
    in setName() (a genuinely dimmer-specific field, kept in sync with the
    inherited bleName as before).
    One incidental behavior fix: clearing a dimmer's name (setName("")) now also
    clears the inherited BLE identity (bleName/bleAddress) via retarget(), which
    the o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
    [DimmerBLEClient.cpp]
2026-10-01 Rebase LissabonControllerMod/LissabonRemoteMod onto IotsaBLEClientCollectionMod
    Follows iotsa's split of IotsaBLEClientMod into a lean base (scanner +
    arbiter + registry) and IotsaBLEClientCollectionMod (the human-facing
    REST/web/discovery layer both of these modules actually use -- known-
    device listing, add/remove by name, unknown-device scanning). Both now
    inherit the collection subclass instead of the bare base, with every
    previously base-qualified call (formHandler_fields/_args, getHandler,
    putHandler, loop) re-pointed at IotsaBLEClientCollectionMod instead.
    Replaced setDuplicateNameFilter(true) + setServiceFilter(Lissabon::
    serviceUUID) with an isInterestingUnknownDevice() override on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
    [LissabonControllerMod.cpp, lissabonSimpleRemote.cpp, mainRemote.cpp]
2026-10-01 DimmerBLEClient: document why it skips IotsaRunmodeBLEClient's new command surface
    IotsaRunmodeBLEClient grew its own queueIdentify()/queueReboot()/
    queuePromoteMode()/queueSetWifiDisabled() REST/web surface (iotsa
    cwi-dis/iotsa#264 BLEController work). DimmerBLEClient's getHandler() (and
    putHandler()/formHandler_fields()/formHandler_args()) already qualify all
    the way up to IotsaBLEClientDevice, bypassing it -- deliberately, since
    DimmerBLEClient has its own separate identify path and no use for the
    other three. Comment only, no behavior change.
    [DimmerBLEClient.cpp]
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2026-10-06 Adapt to iotsa's standard modules and per-application authenticator
    Re-vendor iotsa-board-traits.ini / iotsa-board-defs.ini from iotsa
    develop (status LED defines: IOTSA_PIN_LED, IOTSA_LED_NEOPIXEL,
    IOTSA_LED_ACTIVE_LOW).
    - Drop the IotsaWifiMod/IotsaOtaMod declarations: iotsa now creates the
    WiFi and OTA modules automatically (cwi-dis/iotsa#85).
    - Drop the IotsaBLEServerMod declaration: created automatically in BLE
    builds (cwi-dis/iotsa#84).
    - Module constructors no longer take an authenticator: modules use the
    application's one (cwi-dis/iotsa#284).
    [lissabonDimmer.cpp, lissabonLedstrip.cpp, lissabonSimpleLight.cpp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]
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
